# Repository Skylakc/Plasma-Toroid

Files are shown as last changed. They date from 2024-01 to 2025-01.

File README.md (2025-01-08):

# Plasma Toroid DIY Instructions

You can find all the parts for this project in the AliExpress store:
https://www.aliexpress.com/item/1005007423624401.html

or Tindie store:
https://www.tindie.com/stores/simonliu/

For more infomation and cooler gadgets, you can visit our website:
https://haloplasma.com

You can discuss technical issues on Telegram：
https://t.me/+eRFEajIG6_RiMTY1.

[Demo Video](https://youtu.be/MAfQ2tqjaKY)

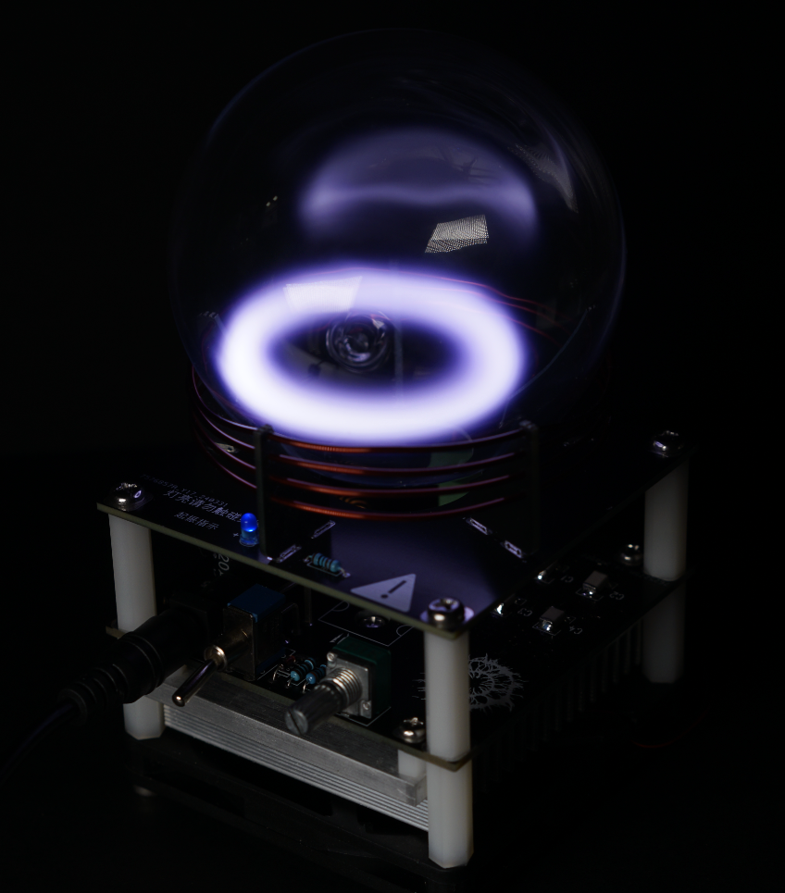
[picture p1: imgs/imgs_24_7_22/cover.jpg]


If you find this document helpful, you can buy me a coffee. We will continue to improve this document.

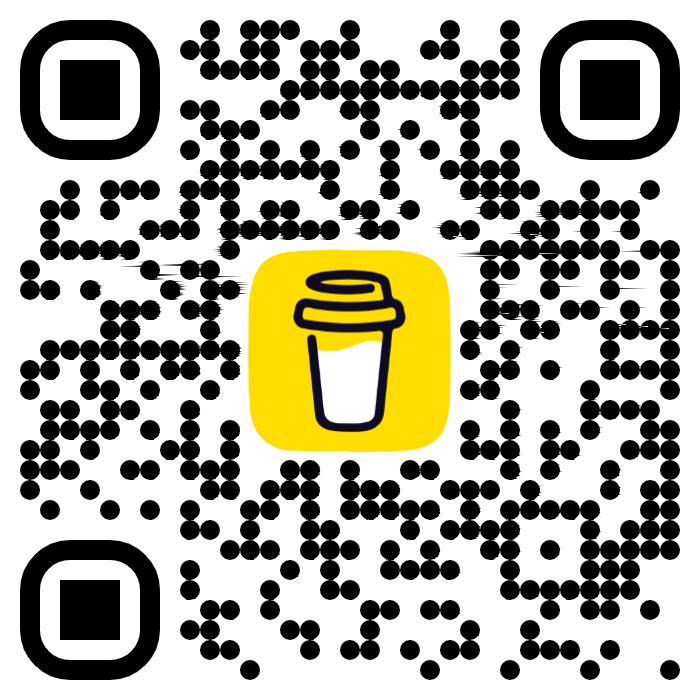
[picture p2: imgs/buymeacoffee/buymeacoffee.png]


## 版权声明©

本仓库版权归属对角巷魔法商店

本仓库遵循 CC-BY-NC-SA协议(即创作共用-署名-非商业性-相同方式共享)且禁止未授权的演绎(截取原工程部分或者在原工程基础上加以修改而诞生的新工程称之为“演绎”)，即使被授权，也要以同样方式共享其工程才方可进行演绎(需要标注原作者署名以及来源)

请大家自觉遵守开源协议，共同维护开源环境。此项目仅供 DIY 以及学习之用，禁止将此项目用于一切商业行为(以牟利为目的贩卖，传播，复制)包括以上三点且不局限于以上三点。

注意!!本产品未授权给任何组织或个人进行销售，如有授权会在此公示。

## 免责声明
在您使用本文档制作等离子环前，请仔细阅读以下重要安全警告和免责说明。使用本文档即表示您已充分了解并同意以下条款：
- 等离子环的危险性：等离子环在运行时玻璃瓶身会产生高温，存在低温烧伤风险。任何时候都不建议用手直接触摸正在运行的玻璃瓶，以免烧伤。
- 磁场警告：等离子环在运行时会产生较强磁场。对于佩戴心脏起搏器及其他医疗设备的人群，强磁场可能会影响设备正常工作。我们建议这部分用户应远离正在工作的等离子环，避免可能的健康风险。
- 高电压风险：等离子环的驱动电路在工作时会产生高电压。高电压存在触电或灼伤的危险，请在电路工作时不要触碰任何元件，包括初级线圈，以免触电或烧伤。
- 元件温度：请注意，电路的某些元件在运行时可能会变得非常热，这可能会造成烫伤。请在设备运行时，特别是长时间运行后，不要触摸这些元件。

使用本文档意味着您已经了解并同意自担使用风险，对于不遵守安全指南而造成的任何直接或间接损害，作者不承担任何责任。

谨慎DIY，安全至上！

## 等离子环（Plasma Toroid）的工作原理解析

  - 辉光放电现象：在特定条件下，气体会在强电场的作用下发生辉光放电。这一过程中，气体分子的电子受激发后跃迁至更高能级轨道。由于这些电子在高能态下并不稳定，它们会自主回落至原始低能轨道，同时根据能量守恒定律释放出能量差对应的光子。这一现象就是辉光放电，它被应用于霓虹灯等装置中。等离子环的发光过程与此类似。

  - 等离子体的性质：除了常见的固体、液体和气态，等离子体是存在于宇宙中的另一种物质状态，火焰便是包含等离子体的例子。当气体受到高温的影响时，分子间的碰撞会使得外层电子脱离其轨道，形成一种由带电粒子组成的等离子体。这种带电的离子混合物具有导电性。
  - 环形电磁场的产生：通过在环形线圈中通入高频交变电流，可以根据麦克斯韦方程组得出其周围电场分布为环形。我们使用自激的Class E震荡电路来生成频率为10MHz左右的交流电。

  - 等离子环的生成过程：在一个封有低压氙气的球形玻璃瓶内，氙气在强电场的作用下被电离，形成等离子体。这些导电的氙气等离子体在外加环形电场的影响下，形成稳定的环状结构。在等离子体中，带电粒子的碰撞产生辉光放电，进而发出淡紫色的光芒，这使得等离子环可见。

**请您在使用和展示等离子环时，确保理解其工作原理和相应的安全措施，以保障使用者的安全。**

## 严正谴责

本项目旨在帮助广大爱好者复现出属于自己的等离子环。然而，近期有无耻商家抄袭此开源项目进行商业行为，严重侵犯本项目著作权。本人在此对此商家的行为进行严正谴责。

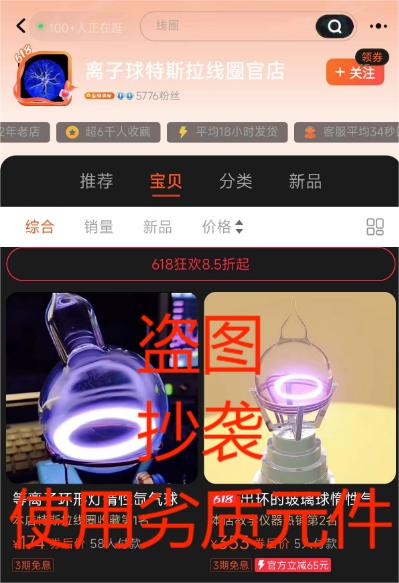
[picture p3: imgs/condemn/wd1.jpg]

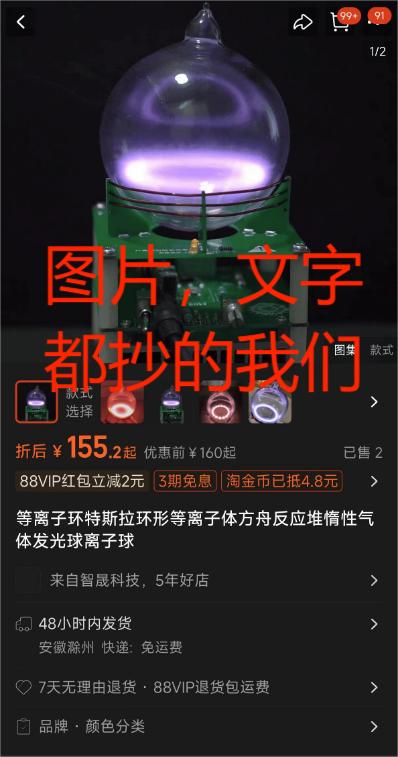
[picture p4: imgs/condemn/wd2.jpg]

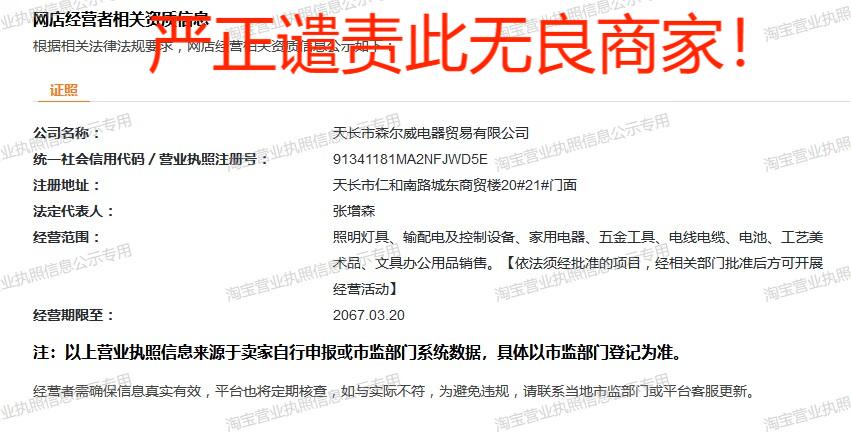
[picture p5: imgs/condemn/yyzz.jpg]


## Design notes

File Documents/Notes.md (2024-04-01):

# 调试过程的注意事项

作者 *对角巷魔法商店*

[成品效果视频](https://www.bilibili.com/video/BV1YQ4y157gs)

[立创开源平台](https://oshwhub.com/skylake/plasmatoroid-drive-circuit)

[装配教程](./Tutorial.md)

等离子环开源技术交流QQ群 736688139

在将自己的制作资料开源后，我收到了很多的反馈，一些制作与调试的经验总结如下，帮助大家少走弯路。

## 从哪里获取制作资料

最开始我在github，立创平台，b站均发布了教程，但后二者每次修改后审核周期漫长，若要获取最新教程请前往github，部分朋友反应打不开github链接，可能是需要梯子。没有梯子可以前往立创平台，立创平台每次更新会审核2天，期间无法看到资料。另外，有问题获得答案的最快方法是加群直接问我。

## 从哪里买到氙气玻璃球

淘宝有两家售卖氙气玻璃球的，一家价格为400，一家价格为160，两种都可以出环，如果觉得贵，关键词搜索爱迪生玫瑰花灯泡，20元左右的灯泡也可以出环。

## 制作时需要注意的

扼流电感选择方面，可以使用10uH的黄环电感，也可以使用自己手绕的电感，手绕的话在2.5cm直径模具上绕制20圈左右即可，手绕的发热更小些。

调整偏置电压的10k电位器建议选择精密电位器，该电位器对能否起振极为关键，该电位器旨在提供3-4V的直流偏置给到mos管G极。直流偏置过低会不起振，过高会电流过大烧坏mos管，调整此电位器一定要极为谨慎！

为了防止炸管，电源一定要有限流功能。如果没有可调电源，可以购买XL4015模块，将其串联在电源上面，将限流拧至3.5a左右即可大大降低电路故障率。

## 调试中需要注意的

一定要**远离**线圈和电容！那里的高压会对你的手**放电**，皮肤会瞬间烧伤！深可及肉~~烤肉的香气~~

电路不建议长时间工作，即使电路不热，玻璃球也可能会很**烫手**。

**非常缓慢**地拧直流偏置电位器，拧到电路刚好起振即可。

可以使用一个氖泡放到线圈附近检验是否起振，如果起振了氖泡会亮。

起振后一般需要用压电陶瓷的高压激发才能出环，成功率最高的激发方法是一个手扶住球上面，另一个手向靠近线圈的位置打火。调整得很好的电路也可以实现自启动。

## 此项目更新状况

目前我们开发出了多个新功能，将会逐步融合到电路里并开源，这些功能已经在实验室里测试成功，但PCB制造出来验证还需要一段时间。

通过在直流偏置处耦合入音频信号，环可以随音乐跳动。
PCB线圈出环成功，使用PCB线圈可以避免手绕线圈的不一致。

通过控制bias电压，可以实现自启动。
氖气玻璃球也可以驱动，拥有极度闪耀的红色

通过调制母线电压和bias，等离子环会产生更多形状
下一版的PCB已经在路上了，在调试成功后这些功能会逐步加入到github项目中，欢迎朋友们加群持续关注。

---

您的Star是对此项目最大的支持!

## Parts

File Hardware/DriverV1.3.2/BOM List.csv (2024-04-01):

Comment | Description | Designator | Footprint | LibRef | Quantity
1K |  | 1K | 1W 金属膜 | 1W 电阻 | 2
RK097 |  | 1K | RK097 电位器 |  | 1
1N4739 | 稳压二极管 | 1N4739 | DO-41 | 稳压二极管 | 1
Resistor |  | 2.7K | 1/4W 金属膜 | 1/4W 电阻 | 1
Resistor |  | 5.6K | 1/4W 金属膜 | 1/4W 电阻 | 1
220uF |  | 220uF | 10MM 电容 | 10mm 电解 | 2
472 | 贴片电容 | 472 | 1812_C | 1206 电容 | 2
330 |  | C1, C2, C3, C4 | 10MM 瓷片 | 10MM 瓷片电容 | 4
FAN |  | FAN | HX2.54-2 | HX-2.54 | 1
10uH |  | L1 | 6826 卧 | 6826电感 | 1
IRFP260 | MOS(场效应管) | MOS | TO-247卧式A | NMOS | 1
OUTPUT |  | OUTPUT | KF142R-3 | HX-2.54 | 1
INPUT |  | P2 | DC005 | HX-2.54 | 1
P6KE15CA | 双向TVS | P6KE15CA | DO-15 TVS | TVS | 1
Switch |  | S1 | MS102-C4 |  | 1
M4*30 | 单头六角尼龙柱 |  |  |  | 4
M4*30 | 平头六角尼龙柱 |  |  |  | 4
M4*30 | 螺钉 |  |  |  | 4
M4*5 | 螺钉 |  |  |  | 4
M3*6+6 | 铜柱
M3*5 | 螺钉
M3*10 | 螺钉
打火机点火器
TO-247导热垫

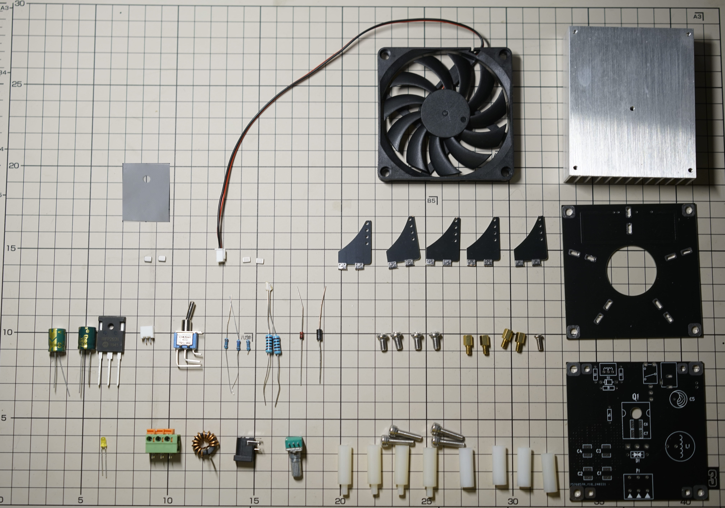
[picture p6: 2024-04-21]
imgs/imgs_24_4_13/FullComponents.JPG

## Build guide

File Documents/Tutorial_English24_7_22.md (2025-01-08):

# Plasma Toroid DIY Instructions

This document was updated on Sep 14, 2024.

Author: *Diagon Alley Magic Shop*

All components used in this document can be found in the Aliexpress store ***Diagon Alley Magic Shop***. 

[Aliexpress link](https://www.aliexpress.com/item/1005007423624401.html)

[Plasma Toroid Principle](https://www.youtube.com/watch?v=GbMAvn7nRWo)

[Finished product demo video YouTube](https://youtu.be/MAfQ2tqjaKY)

[Cooler gadgets in our website](https://haloplasma.com) 

Plasma toroid open source technology telegram group:
https://t.me/+eRFEajIG6_RiMTY1



## Copyright Notice©

This document is for personal learning and plasma toroid manufacturing only. Without the author's consent, no one may modify, republish, or distribute the content of this document. It is strictly prohibited to use this document for any commercial activities.

## Disclaimer
Before using this document to make a plasma toroid, please carefully read the following important safety warnings and disclaimers. Using this document means that you fully understand and agree to the following terms:
- Dangers of plasma toroids: The glass bottle will generate high temperatures when the plasma toroid is running, and there is a risk of low-temperature burns. It is never recommended to directly touch the running glass bottle with your hands to avoid burns.
- Magnetic field warning: The plasma toroid will generate a strong magnetic field during operation. For people wearing pacemakers and other medical devices, strong magnetic fields may affect the normal operation of the devices. We recommend that these users stay away from working plasma toroids to avoid potential health risks.
- High voltage risk: The drive circuit of the plasma toroid will generate high voltage during operation. High voltage poses a danger of electric shock or burns. Please do not touch any components, including the primary coil, while the circuit is working to avoid electric shock or burns.
- Component temperature: Please note that some components of the circuit may become very hot during operation, which may cause burns. When the device is running, especially after running for a long time, do not touch these components.
- Electromagnetic interference: The plasma toroid will emit electromagnetic waves around 10MHz when running. This band will not harm the human body, but it may interfere with some electronic devices operating in this band, such as touchpads and card readers. Please keep these devices away from the working drive circuit.

Using this document means that you understand and agree to bear the risks of use. The author is not responsible for any direct or indirect damages caused by not following the safety guidelines.

DIY with caution, safety first!

## Analysis of the Working Principle of Plasma Toroids

  - Glow discharge phenomenon: Under certain conditions, the gas will undergo glow discharge under the action of a strong electric field. In this process, the electrons of the gas molecules are stimulated and jump to higher energy level orbits. Since these electrons are unstable in the high-energy state, they will spontaneously fall back to the original low-energy orbit while releasing photons corresponding to the energy difference according to the law of conservation of energy. This phenomenon is called glow discharge and is applied to devices such as neon lights. The luminescence process of plasma toroids is similar to this.

  - Properties of plasma: In addition to the common solid, liquid, and gas states, plasma is another state of matter that exists in the universe, and flames are an example that contains plasma. When the gas is affected by high temperature, collisions between molecules will cause the outer electrons to escape their orbits, forming a plasma composed of charged particles. This charged ion mixture has electrical conductivity.
  - Generation of toroidal electromagnetic field: By passing a high-frequency alternating current through a toroidal coil, it can be derived from Maxwell's equations that the electric field distribution around it is toroidal. We use a self-excited Class E oscillator circuit to generate an alternating current with a frequency of about 10MHz.

  - Generation process of plasma toroid: In a spherical glass bottle filled with low-pressure xenon gas, the xenon gas is ionized under the action of a strong electric field to form a plasma. These conductive xenon gas plasmas form a stable toroidal structure under the influence of an external toroidal electric field. In the plasma, collisions of charged particles produce glow discharge, which emits a pale purple light, making the plasma toroid visible.

**When using and demonstrating the plasma toroid, please ensure that you understand its working principle and corresponding safety measures to ensure the safety of users.**

## Preparation of Materials

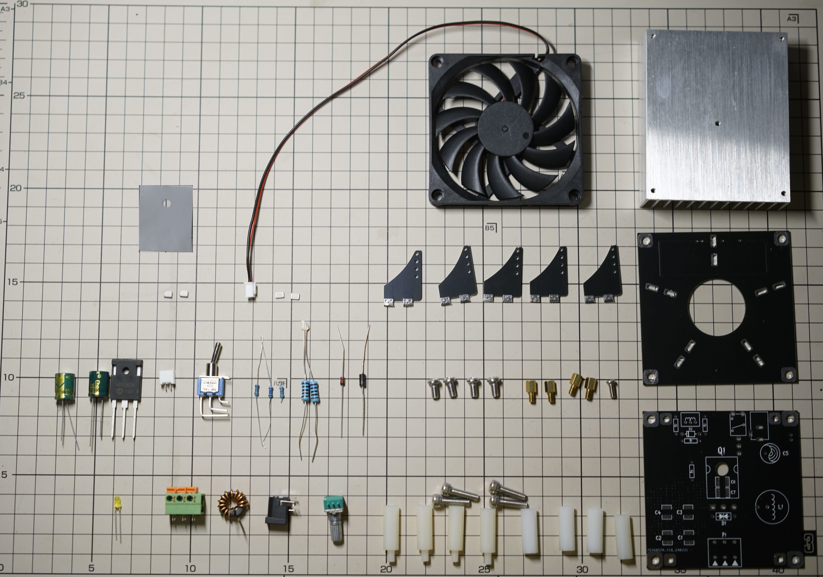
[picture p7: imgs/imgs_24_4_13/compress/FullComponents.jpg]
 

- 80mm glass bottle filled with xenon gas (available in Aliexpress store **Diagon Alley Magic Shop**, larger glass balls cannot be installed in the bracket of this project)
- 1.2mm enameled wire - for winding coils
- Black ring inductor 10uH  
- Circuit board PCB (can be made using the files in the hardware folder)
- Coil support, including base plate and five support pieces
- Heatsink and fan
- MOSFET IRFP260N
- MOSFET heatsink silicone pad
- Potentiometer 1k  
- Resistor 1k * 3
- Resistor 1.8k, 3k
- SMD capacitor 100pf * 4
- SMD capacitor 4.7nF * 2  
- TVS 15V P6KE15CA
- Voltage regulator diode 9.1V
- Input filter capacitor Electrolytic capacitor 63V 220uf
- Toggle switch
- Green terminal block - for connecting coil
- White fan socket
- DC power interface 
- Light emitting diode
- Screws and nylon columns
- Piezoelectric ceramic removed from a lighter (used for initial ignition; this item is prohibited in air transport, so you may need to prepare it yourself, but the circuit can still be made without it)
- XL4015 current limiting module (this module is not required if you have an adjustable power supply)
- 24V power adapter (4A or above, or you can use an adjustable power supply)

## Production Tutorial 
Difficulty ★★★☆☆

### Tools
- Multimeter
- Soldering iron
- Solder wire
- Utility knife
- Diagonal pliers
- Hex screwdriver set 
- Tweezers (for soldering SMD capacitors)

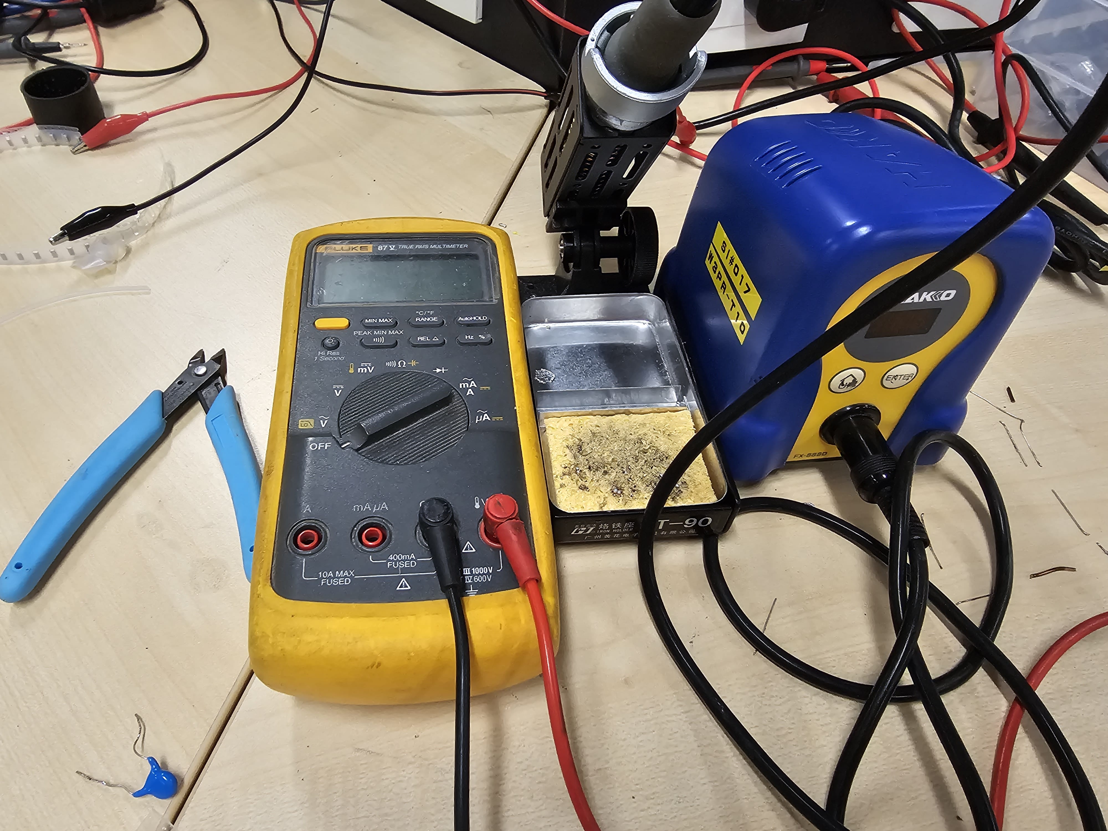
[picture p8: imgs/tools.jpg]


### Steps
- Prepare the five coil brackets, insert them into the base, heat up the soldering iron, and solder them in place with solder. Try to ensure that the brackets are perpendicular to the base plate. (The five coil bracket pieces need some force to fit in)

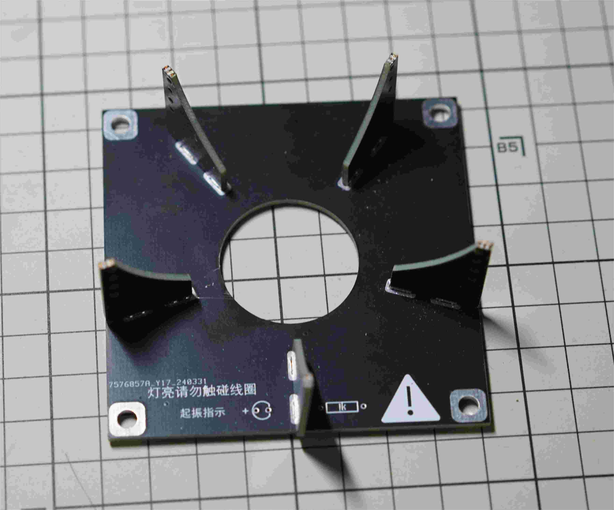
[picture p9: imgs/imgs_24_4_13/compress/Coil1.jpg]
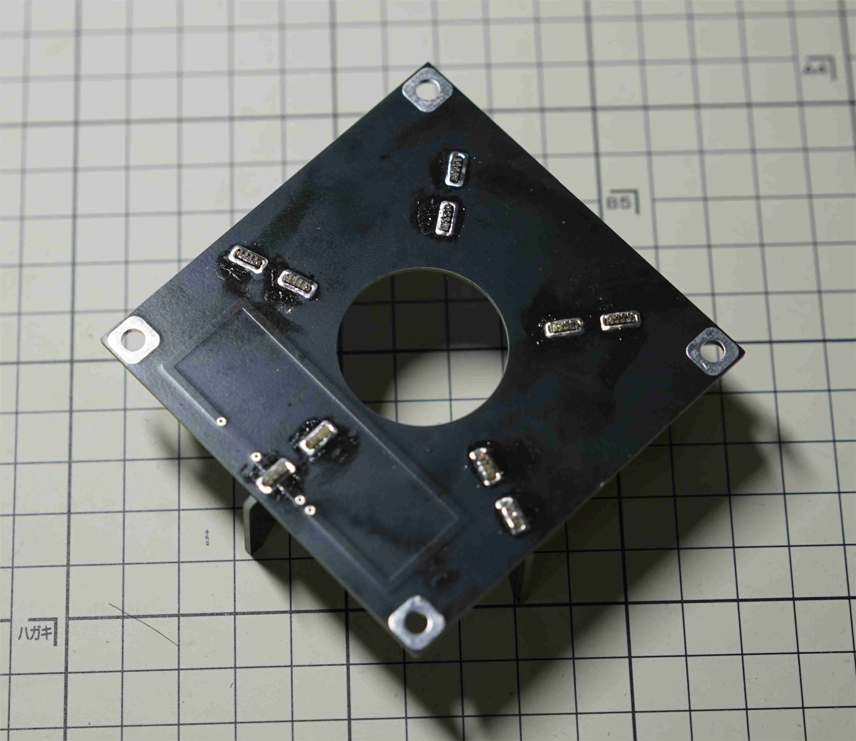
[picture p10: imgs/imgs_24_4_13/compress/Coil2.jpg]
 

- Bend the enameled wire according to the diameter of the coil frame, do not straighten the enameled wire, keeping the enameled wire bent helps with threading, once straightened it cannot be threaded.

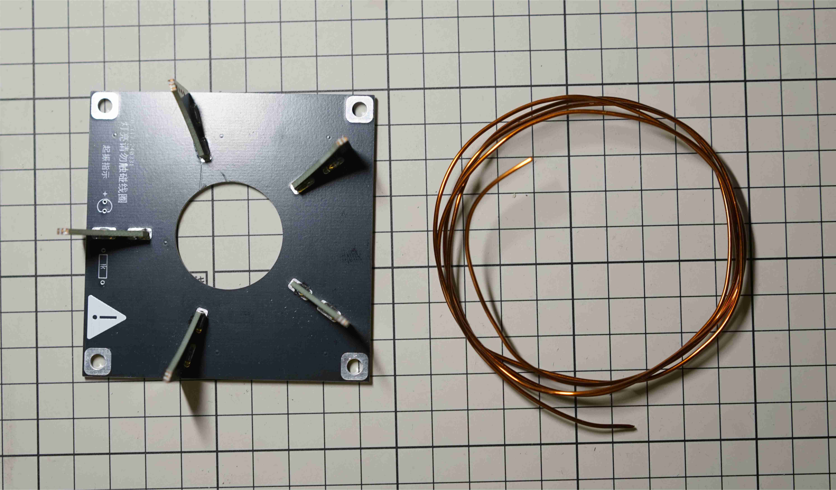
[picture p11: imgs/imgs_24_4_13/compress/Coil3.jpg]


- Thread the enameled wire through the small holes from top to bottom, a total of four turns. The holes are relatively small, and threading can be done by pushing and pulling.

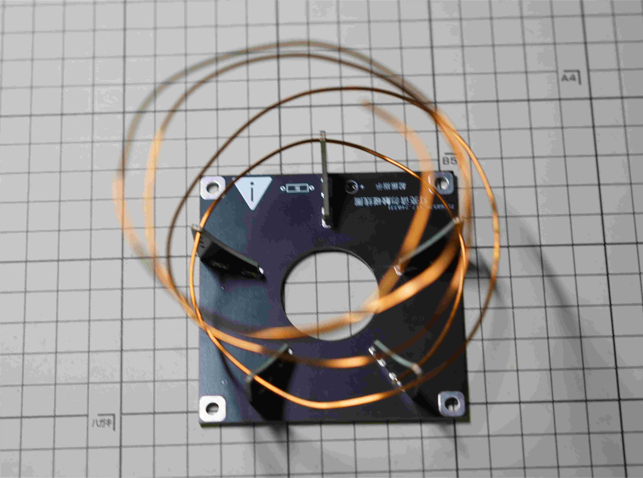
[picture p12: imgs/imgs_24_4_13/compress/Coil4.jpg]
 
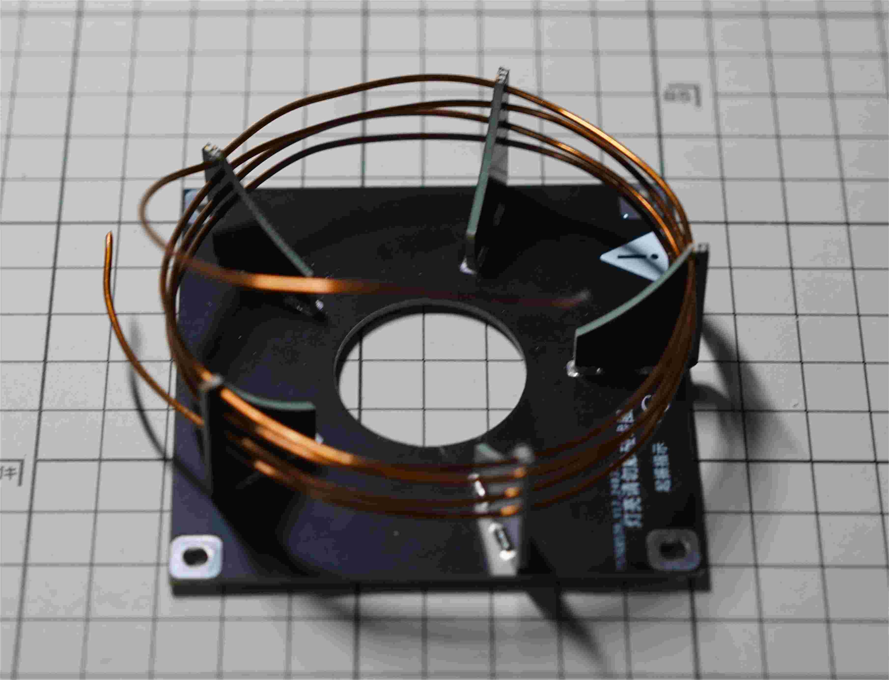
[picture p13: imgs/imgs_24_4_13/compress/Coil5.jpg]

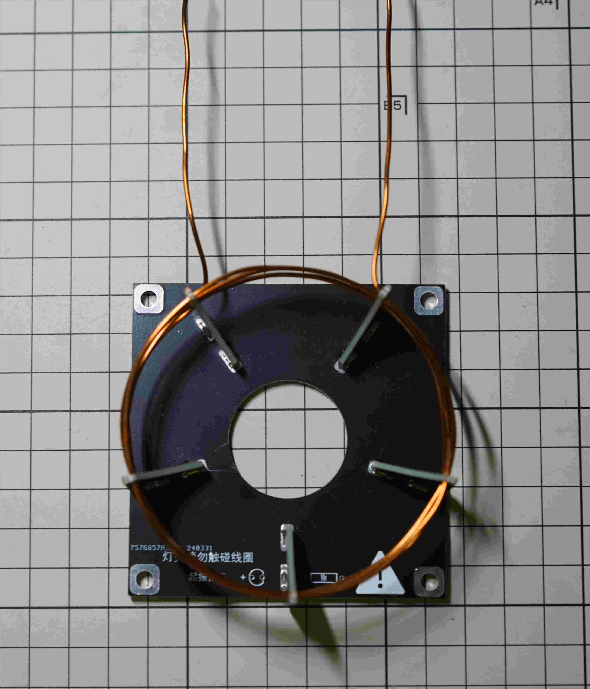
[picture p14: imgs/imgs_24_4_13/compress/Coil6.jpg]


- Make a power supply with current limiting protection (this step can be skipped if you already have an adjustable power supply), prepare a 24V power supply and XL4015 current limiting module, cut the power cord, connect the module in series in the middle, turn the potentiometer for adjusting the output voltage of the XL4015 module clockwise to the end (there will be a clicking sound when turned to the end), and turn the current limiting potentiometer to the 3.5A position. The method to determine the position of the current limiting potentiometer is: set the multimeter to the 10A current range, insert the test leads into the 10A hole, touch the two test leads to the output (at this time, the output is shorted, there may be electric sparks but it's okay), the value displayed on the multimeter is the current limiting value of the current limiting module. Note that using a power supply without current limiting can easily burn out the MOSFET, you must connect the XL4015 module in series before connecting power. If you already have an adjustable power supply, you can skip this step. In the picture below, the potentiometer on the left side of the module is for adjusting the output voltage, and the potentiometer on the right is for adjusting the current limit. Turning clockwise increases the value.
- If you are using an adjustable power supply, please use the current limiting mode (CC), set the output voltage to 24V, and the current limit to 3.5A.

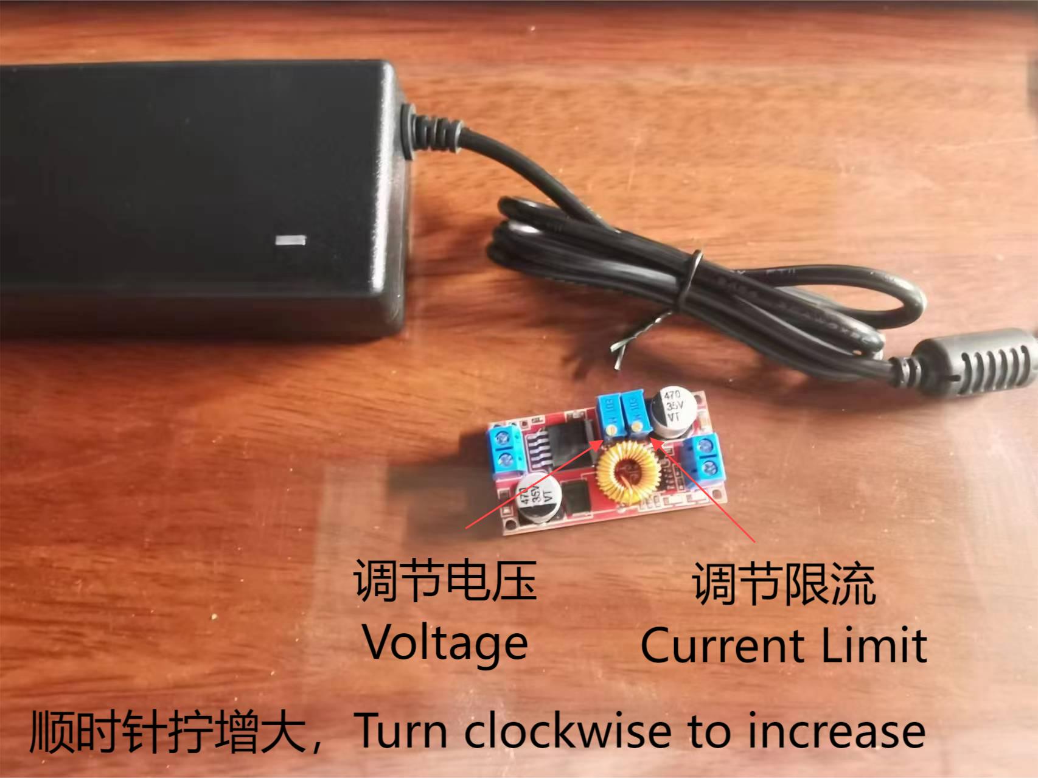
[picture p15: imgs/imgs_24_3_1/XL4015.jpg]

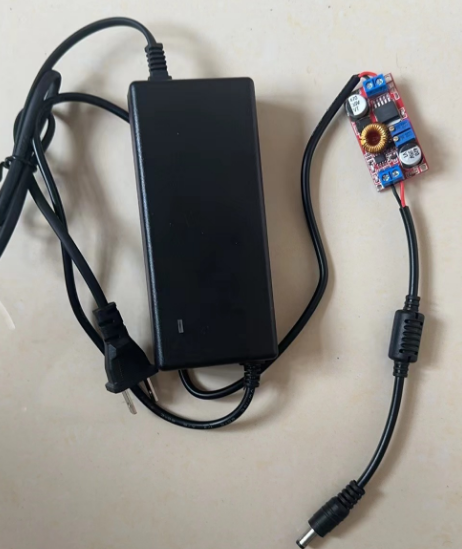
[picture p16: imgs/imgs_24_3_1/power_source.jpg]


- Insert components into the circuit board according to their type (do not install the MOSFET yet). For easy soldering, you can slightly bend the pins to fix them. Note that **the fan connector should be mounted on the back of the PCB, and a light-emitting diode and 1k resistor should also be soldered on the coil bracket PCB**.
The installation positions of each component are shown in the table below.

| Component Name | Installation Position |
|---|---|
| 1k resistor * 3 | R1, R4, coil bracket PCB |
| Light emitting diode | coil bracket PCB |
| 3k resistor | R2 |
| 1.8k resistor | R3 |
| Voltage regulator diode| D2 |
| TVS (black) | D1 |
| Green terminal block | P1 |
| White terminal block | P3 (mounted on the back) |
| 220uf electrolytic cap | C5 |
| 100pf capacitor * 4 | C1, C2, C3, C4 |
| 4.7nf capacitor * 2 | C6, C7 |
| 10uH inductor | L1 |
| IRFP260 | Q1 (do not install this yet) |
| Switch | |
| DC5525 black power jack| |
| B1K single potentiometer | |

- It is recommended to solder the shorter components first, then the taller components, such as soldering the SMD capacitors, resistors, voltage regulators, terminal blocks, etc. first, and finally soldering the electrolytic capacitors and switch. If you have no soldering experience, be sure to search for soldering tutorials on Bilibili to learn first. According to historical statistics, 60% of people who had problems after making it were due to poor contact between components and PCB caused by not mastering the correct soldering method.
  
  > Resistor identification 
  >  - 1k resistor has a brown line
  >	 - 1.8k resistor has a brown line and a gray line  
  >	 - 3k resistor has an orange line
  >	 If you really can't tell them apart, just measure with a multimeter ^_^

  > Capacitor identification
  >  - 4.7nF capacitors are relatively thinner
  >	 - 220pF/100pF capacitors are relatively thicker
  >  - For resonant capacitors, you can choose two 220pF or four 100pF

  > Diode direction identification
  >  - The black TVS is non-directional
  >	 - The red voltage regulator diode needs to be directional, the black line on the voltregulator diode should match the white line position on the PCB silkscreen.age 

  > Some friends may not know how to solder SMD components, you can search for SMD component soldering tutorials on Youtube to learn. Simply put, solder one side first to fix the SMD component, then solder the other side.
  >【How To Solder SMD Correctly - Part 1 /SMD Soldering Tutorial - Youtube】 https://www.youtube.com/watch?v=EW9Y8rDm4kE

  > Be sure to pay attention to the direction of the electrolytic capacitor, soldering it backwards may cause intense heating or even explosion. The longer leg of the electrolytic capacitor is the positive electrode, and the side with the stripe mark is the negative electrode. Please refer to the picture below to install the electrolytic capacitor correctly.

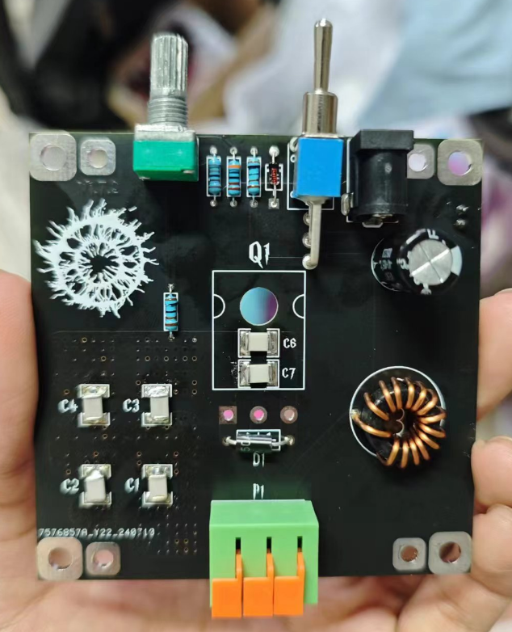
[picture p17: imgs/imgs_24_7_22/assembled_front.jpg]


- When soldering, **be careful of the high temperature of the soldering iron to avoid burns.**

- After all components are soldered, cut off the pins. Please try to ensure that the solder joints are full and smooth, and start from the root when removing the pins.

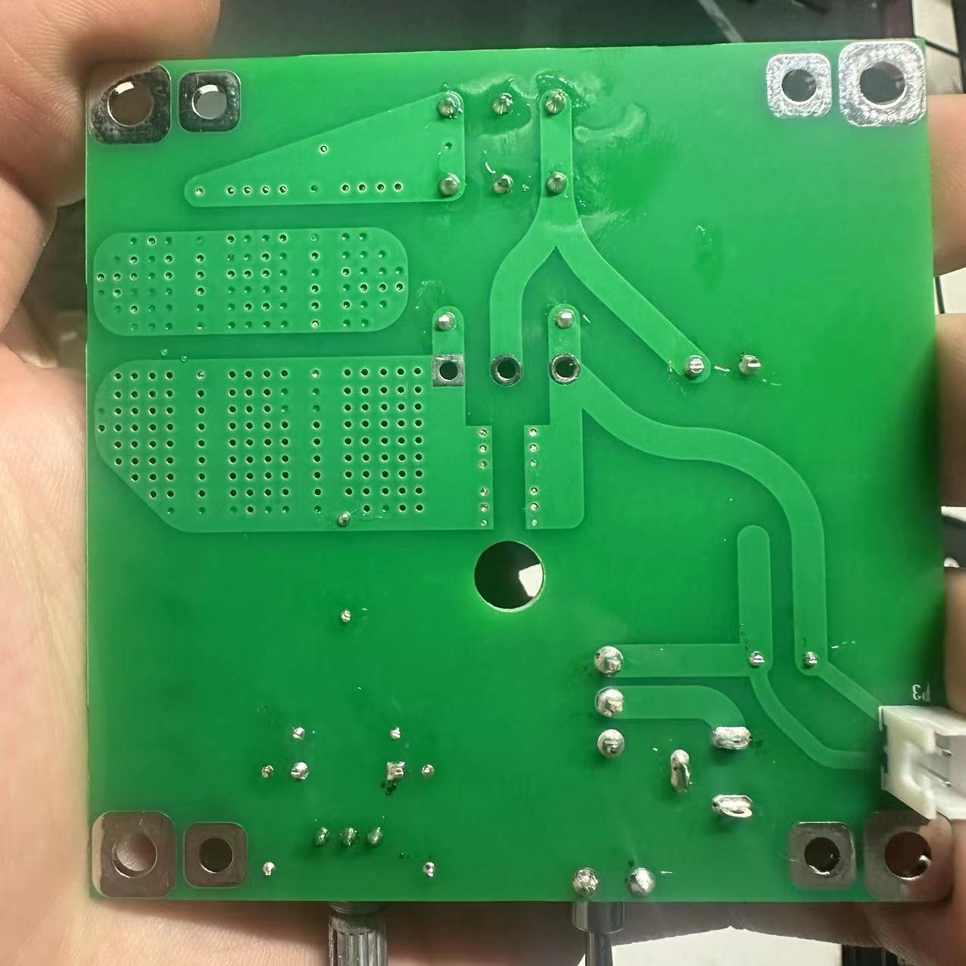
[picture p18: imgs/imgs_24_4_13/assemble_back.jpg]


- Screw 6mm copper columns (or 6mm nylon columns) into the screw holes around the heatsink.

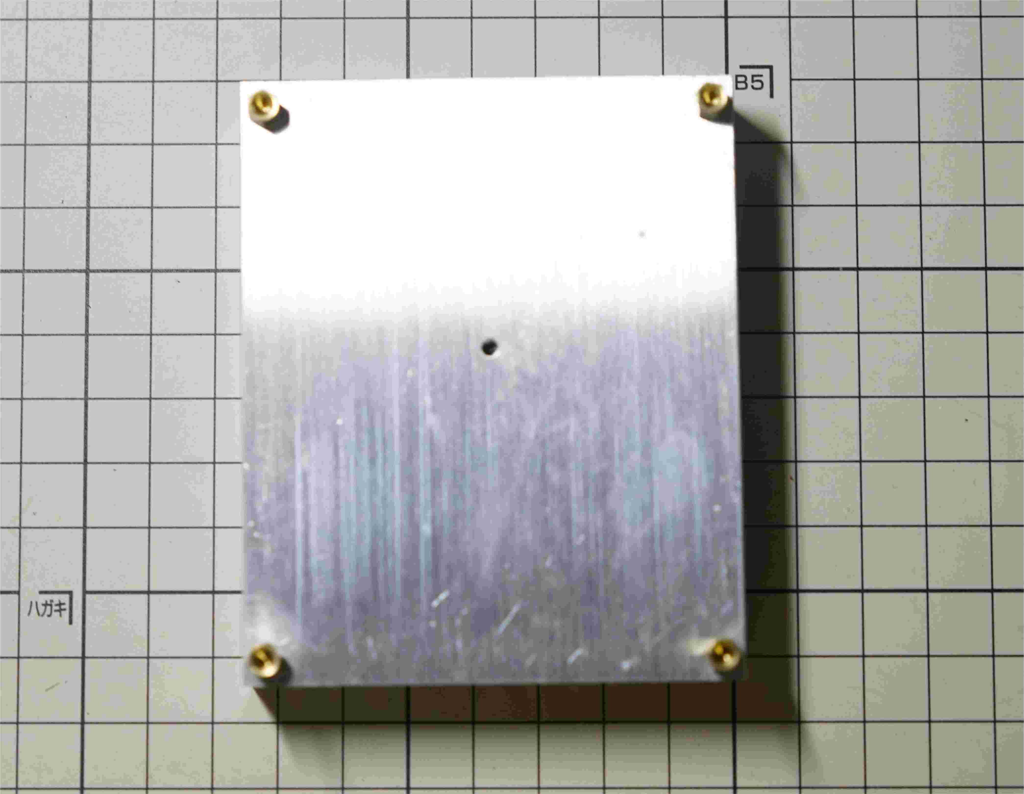
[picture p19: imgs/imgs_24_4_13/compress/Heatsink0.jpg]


- Install the MOSFET. Place the side of the MOSFET with text **facing up**, pad the other side with a silicone pad and fix it on the heatsink with screws, with the pins **facing downward**. At this time, the pins from left to right are G, D, and S poles respectively.

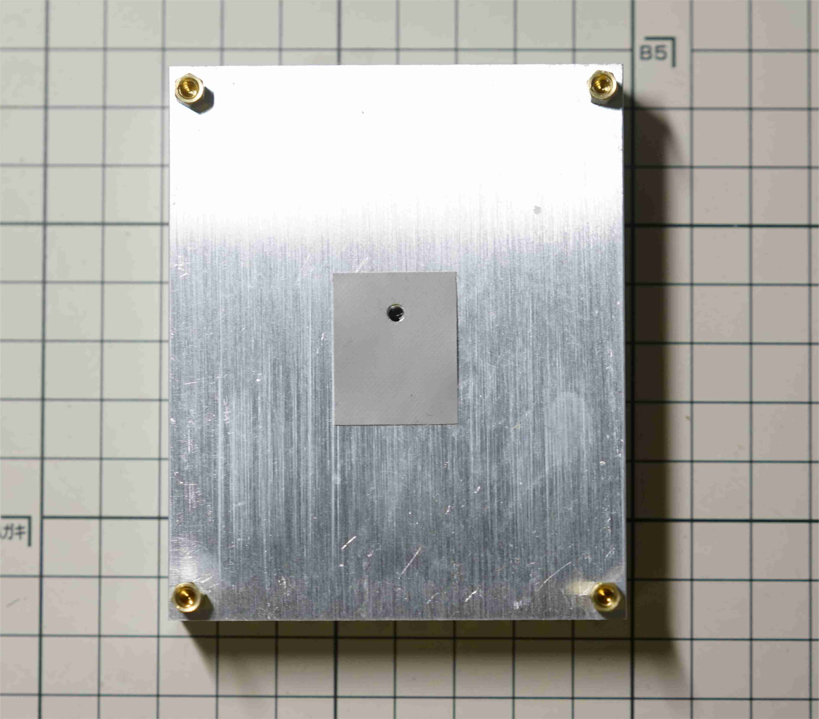
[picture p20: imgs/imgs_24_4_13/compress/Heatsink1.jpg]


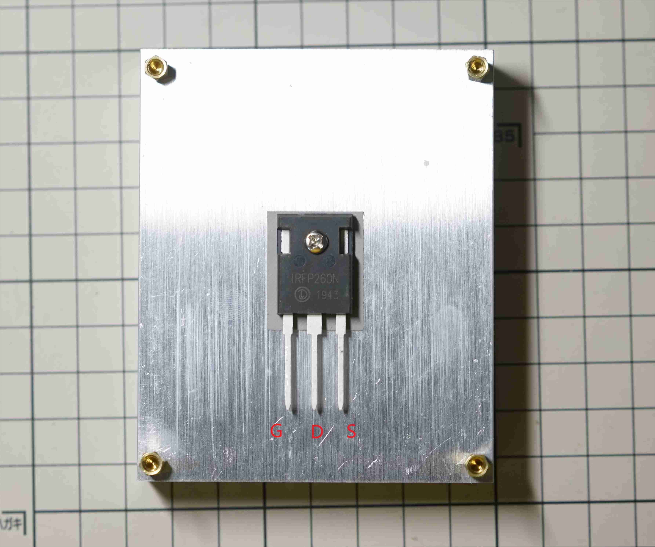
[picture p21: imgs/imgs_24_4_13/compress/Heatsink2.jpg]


- Bend the pins and insert them into the PCB. **First align the holes of the PCB and the heatsink to ensure that the four screws can be tightened**, then solder the MOSFET.

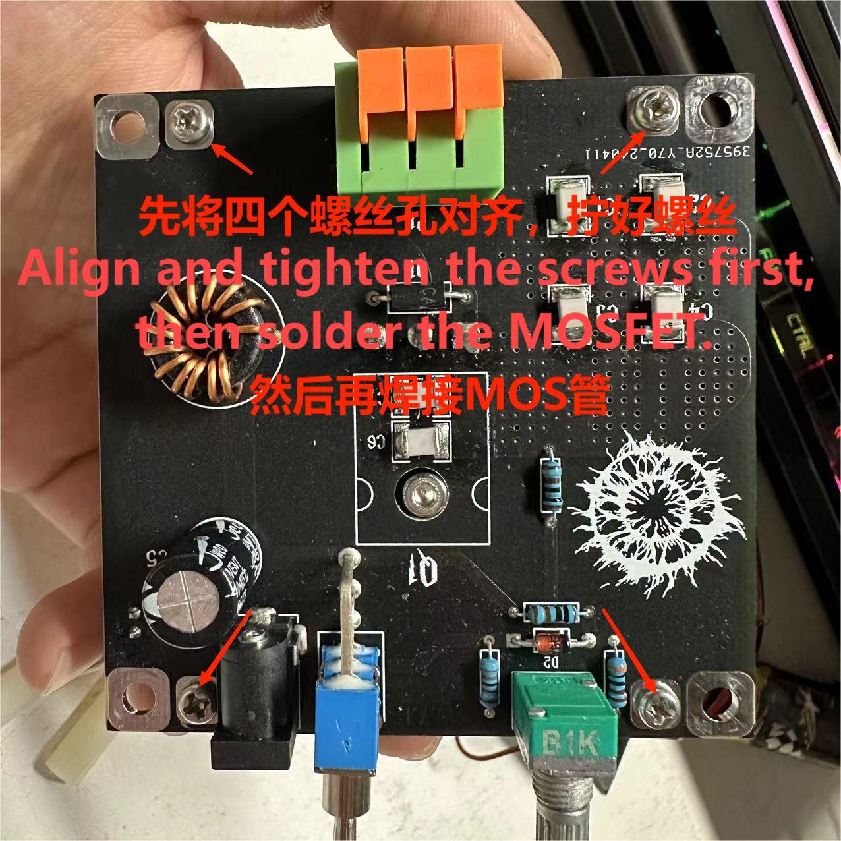
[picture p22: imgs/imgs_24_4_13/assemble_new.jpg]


- Fix the fan. The connection of all layers is shown in the figure below. The fan's airflow is blowing towards the heatsink (blowing upward).

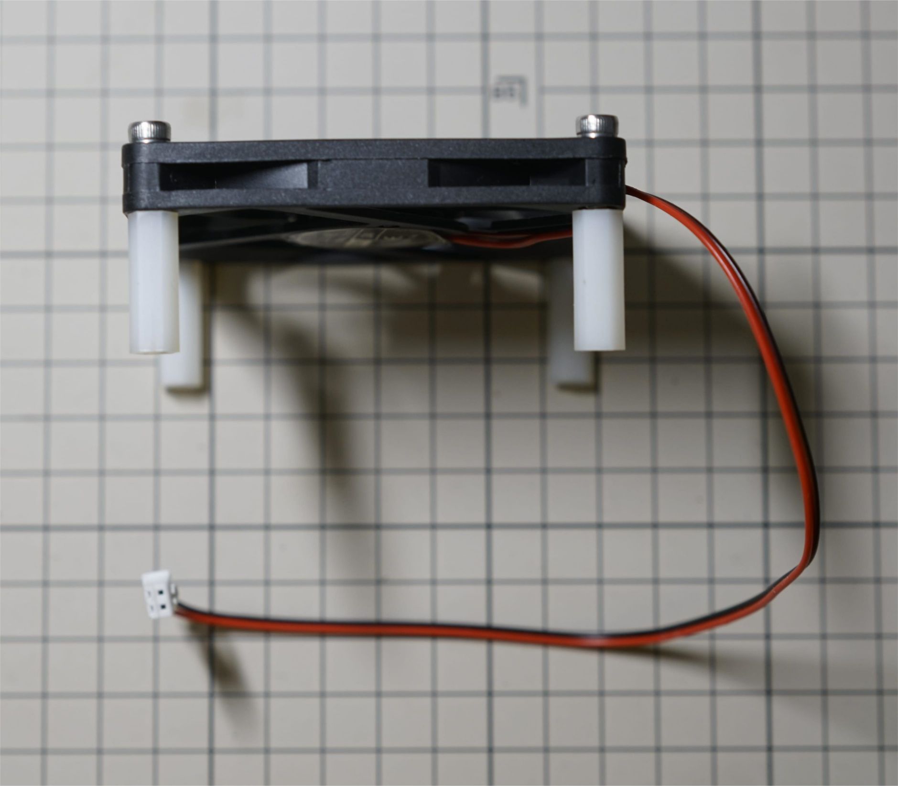
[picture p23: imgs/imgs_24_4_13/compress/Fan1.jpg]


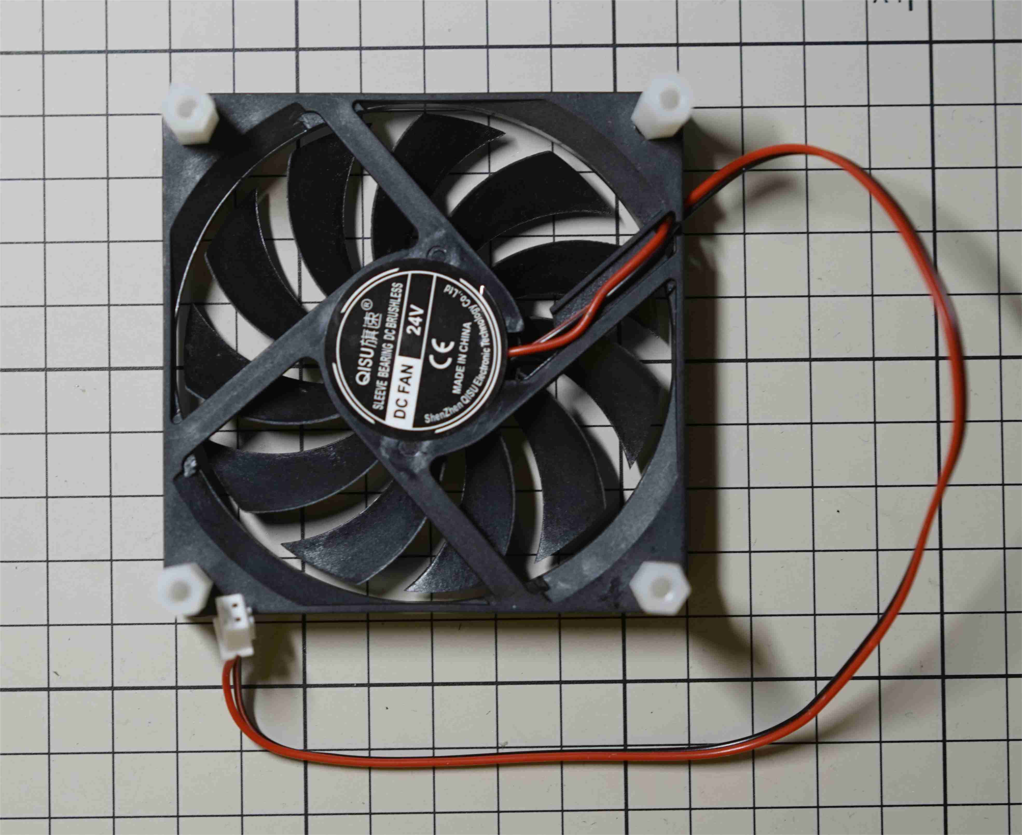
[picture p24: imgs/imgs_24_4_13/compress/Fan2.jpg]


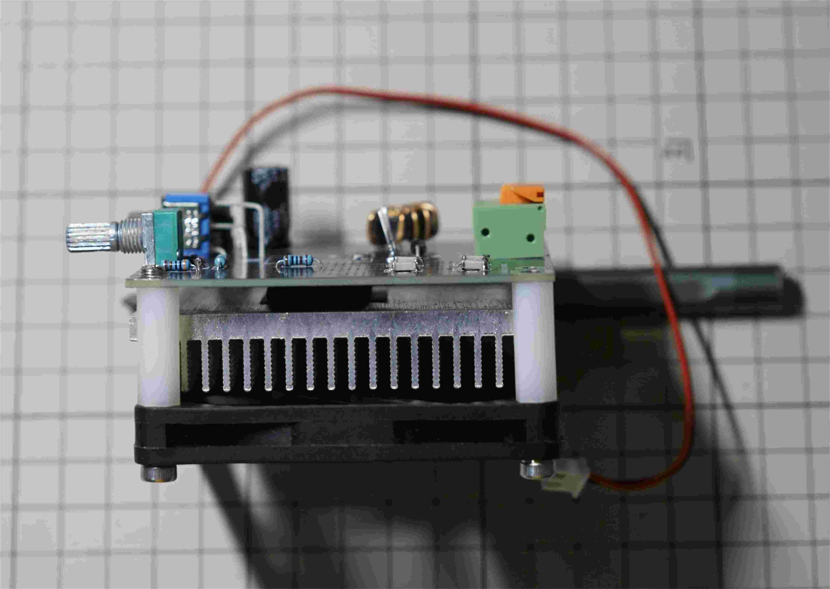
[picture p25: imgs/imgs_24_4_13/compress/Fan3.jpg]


- Use screws to mount the coil bracket to the top, with the two wires facing the green coil terminal block.

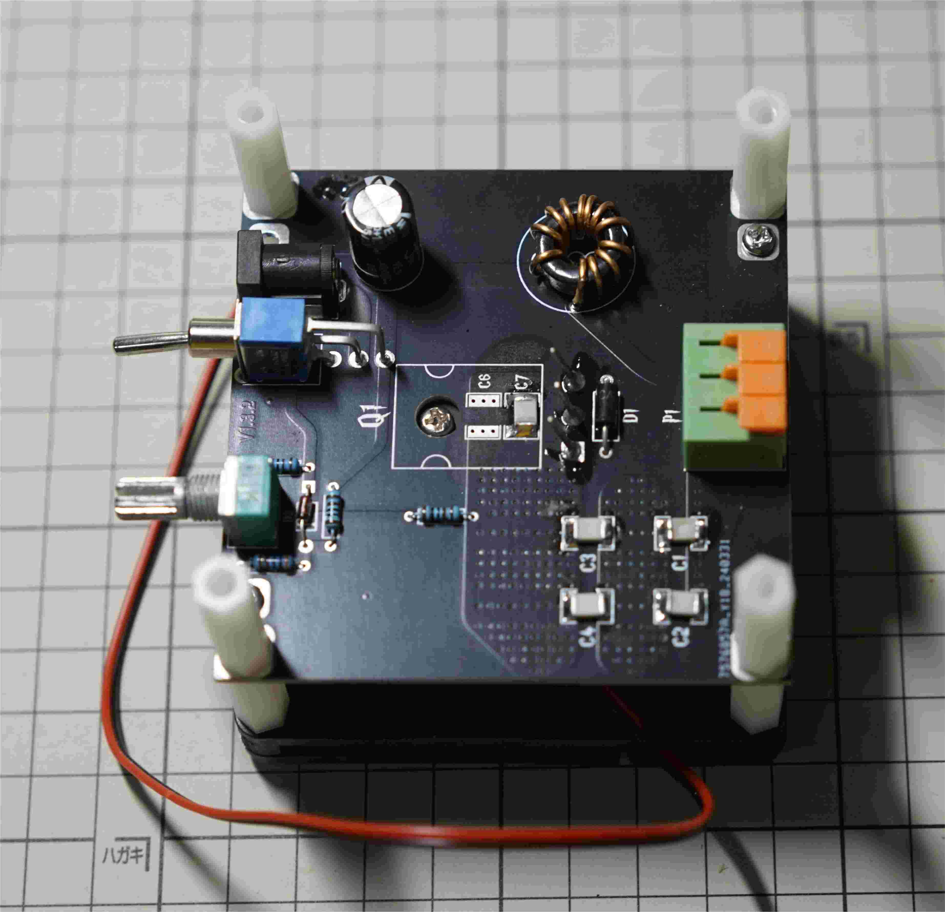
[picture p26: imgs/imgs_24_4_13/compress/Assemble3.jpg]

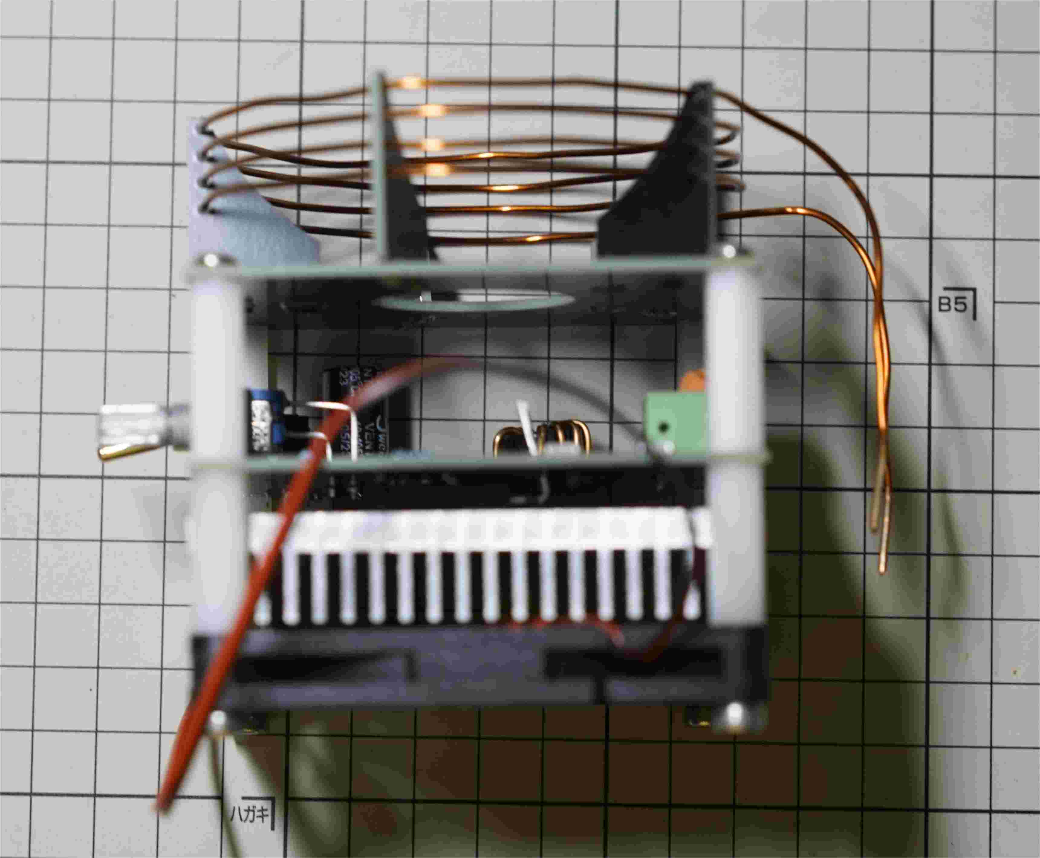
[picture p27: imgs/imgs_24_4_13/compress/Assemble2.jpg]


- Cut the enameled wire appropriately so that it can be inserted into the terminal block.
- Use a utility knife to scrape off the enamel at the end of the wire to expose the copper core inside the enameled wire.
- **Note: Be sure to scrape the enamel at the end of the wire clean, otherwise poor contact may prevent it from working!**

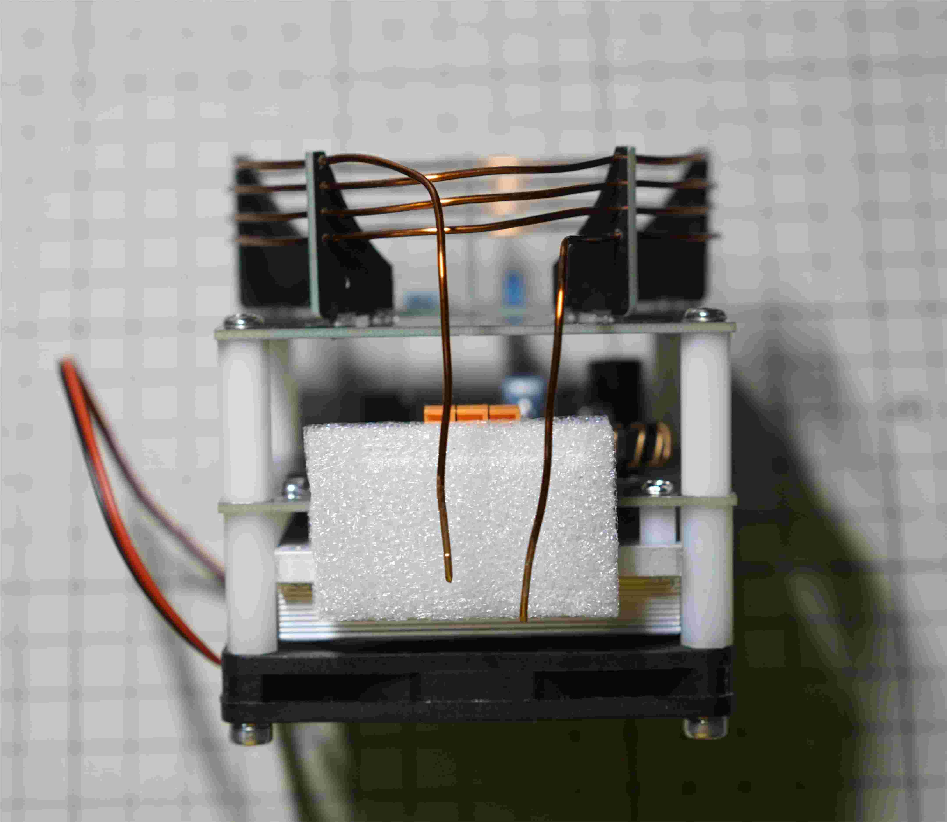
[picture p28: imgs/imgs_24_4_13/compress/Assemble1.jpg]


- Insert the two wires of the coil into pins 1 and 3 of the green terminal block (the middle hole is not used), and insert the fan power cord into the fan interface on the back of the PCB.

- After confirming that all parts are properly connected again, you can prepare to power on o(*￣▽￣*)ブ

- If you are using an adjustable power supply, please use the current limiting mode (CC), set the output voltage to 24V, and the current limit to 3.5A.
- Put on the bottle and make sure the potentiometer is at the maximum counterclockwise position.

- Before powering on, please carefully read the safety instructions:
  >  Stay away from the coil when the circuit is working, as the high temperature of the coil may cause burns.

  >  You can rotate the bottle, but the bottle will also heat up. Be careful and keep your hands away from the coil (at least 1cm away) when rotating the bottle.

  >	 You can turn the potentiometer while the circuit is working, but do not hold the bottle with one hand and touch the potentiometer on the circuit with the other hand, because the high-voltage static electricity on the bottle can damage the circuit.

  >	 The circuit will heat up. It is not recommended to run the circuit for a long time. It is recommended to work continuously for no more than two minutes.

  >	 After use, remember to turn off the switch and disconnect the power supply.

- After ensuring that you have read the safety instructions, plug in the power supply and turn on the switch. At this time, the fan should start spinning.

- Turn the potentiometer clockwise. When it is turned about halfway, the circuit will start working. When the circuit starts working, the LED next to the coil will light up. At this point, use a lighter to point at the bottle and click it to generate the toroid. If the lighter fails to generate the toroid, you can turn the potentiometer clockwise a little more and try again.
  
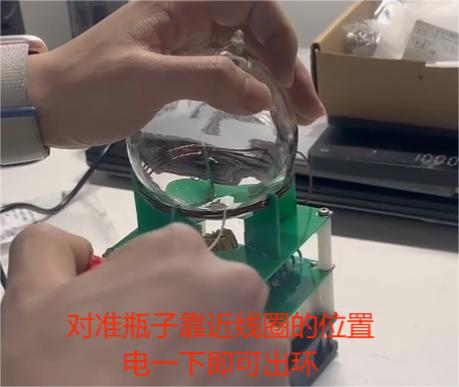
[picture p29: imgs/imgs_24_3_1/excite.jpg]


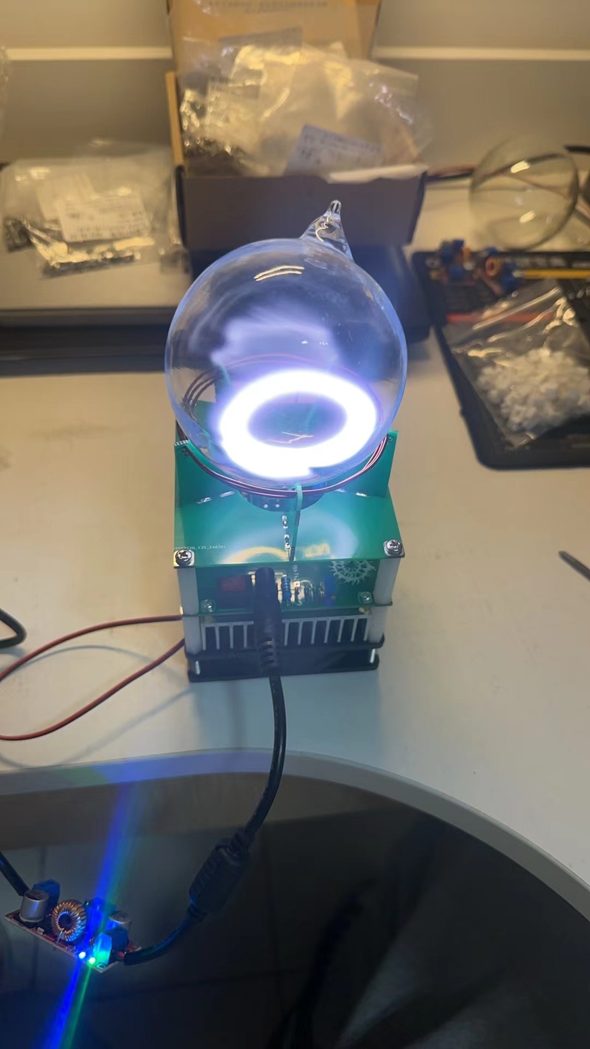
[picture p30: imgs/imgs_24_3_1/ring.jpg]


- Sometimes, your bottle may glow white without generating a toroid (as shown below). Adjusting the bottle position and re-igniting it a few times usually fixes it.

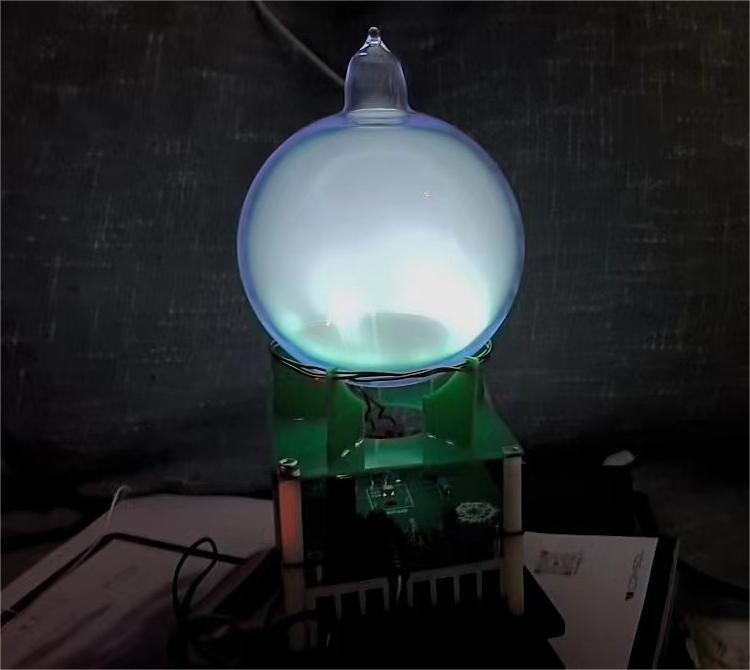
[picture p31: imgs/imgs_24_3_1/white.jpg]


- After the toroid is generated, slightly turning the potentiometer will cause some changes in the shape of the toroid. If the toroid disappears, re-igniting it will generate it again.

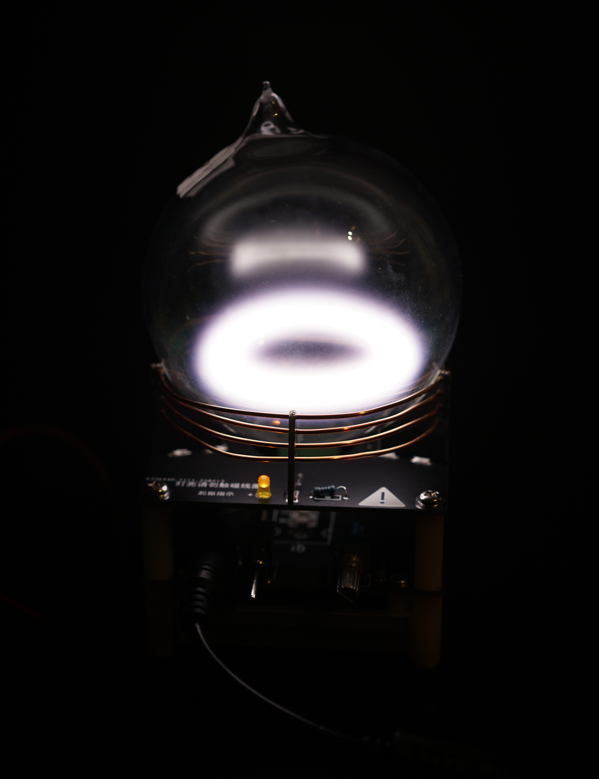
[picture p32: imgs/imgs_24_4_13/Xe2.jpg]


### Reference Circuit Diagram
Since the hardware of this project is still being updated, the circuit diagram is for reference only. The actual circuit should be based on the PCB.
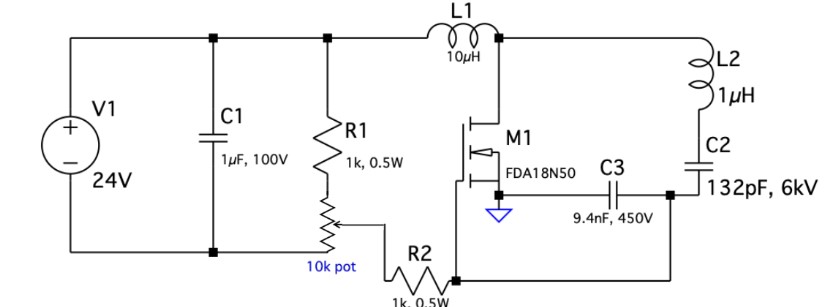
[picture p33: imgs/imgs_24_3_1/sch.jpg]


### FAQ
If you have any questions, join the telegram group：
https://t.me/+eRFEajIG6_RiMTY1.
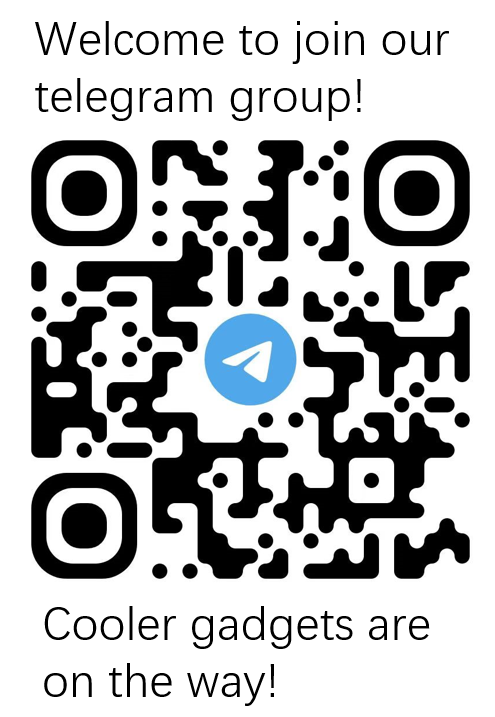
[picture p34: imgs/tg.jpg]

All project developers are in the group, and you can get answers at the fastest speed.(We try to answer all your questions within 24 hours.)

#### Acknowledgments: 
Tate McAluney

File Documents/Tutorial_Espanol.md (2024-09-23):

# Instrucciones de bricolaje del toroide de plasma

Este documento fue actualizado el 22 de julio de 2024.

Autor: *Tienda de Magia del Callejón Diagon*

Todos los componentes utilizados en este documento se pueden encontrar en la tienda de Aliexpress ***Tienda de Magia del Callejón Diagon***. 

[Principio del toroide de plasma](https://www.youtube.com/watch?v=GbMAvn7nRWo)

[Video de demostración del producto terminado 1](https://www.bilibili.com/video/BV1Lm411z7tf)

[Video de demostración del producto terminado 2](https://www.bilibili.com/video/BV12f421o7rf) 

[Plataforma de código abierto LCEDA](https://oshwhub.com/skylake/plasmatoroid-drive-circuit)

Grupo de telegram de tecnología de código abierto del toroide de plasma:
https://t.me/+eRFEajIG6_RiMTY1



## Aviso de derechos de autor©

Este documento es solo para aprendizaje personal y fabricación de toroides de plasma. Sin el consentimiento del autor, nadie puede modificar, republicar o distribuir el contenido de este documento. Está estrictamente prohibido utilizar este documento para cualquier actividad comercial.

## Descargo de responsabilidad  
Antes de usar este documento para hacer un toroide de plasma, lea atentamente las siguientes advertencias de seguridad importantes y descargos de responsabilidad. El uso de este documento significa que comprende y acepta completamente los siguientes términos:
- Peligros de los toroides de plasma: La botella de vidrio generará altas temperaturas cuando el toroide de plasma esté funcionando, y existe el riesgo de quemaduras a baja temperatura. Nunca se recomienda tocar directamente la botella de vidrio en funcionamiento con las manos para evitar quemaduras.
- Advertencia de campo magnético: El toroide de plasma generará un fuerte campo magnético durante el funcionamiento. Para las personas que usan marcapasos y otros dispositivos médicos, los campos magnéticos fuertes pueden afectar el funcionamiento normal de los dispositivos. Recomendamos que estos usuarios se mantengan alejados de los toroides de plasma en funcionamiento para evitar posibles riesgos para la salud.  
- Riesgo de alto voltaje: El circuito de accionamiento del toroide de plasma generará alto voltaje durante el funcionamiento. El alto voltaje representa un peligro de descarga eléctrica o quemaduras. No toque ningún componente, incluida la bobina primaria, mientras el circuito esté funcionando para evitar descargas eléctricas o quemaduras.
- Temperatura de los componentes: Tenga en cuenta que algunos componentes del circuito pueden calentarse mucho durante el funcionamiento, lo que puede causar quemaduras. Cuando el dispositivo esté funcionando, especialmente después de funcionar durante mucho tiempo, no toque estos componentes.  
- Interferencia electromagnética: El toroide de plasma emitirá ondas electromagnéticas alrededor de 10 MHz cuando esté funcionando. Esta banda no dañará el cuerpo humano, pero puede interferir con algunos dispositivos electrónicos que operan en esta banda, como paneles táctiles y lectores de tarjetas. Mantenga estos dispositivos alejados del circuito de accionamiento en funcionamiento.

El uso de este documento significa que comprende y acepta asumir los riesgos de uso. El autor no se hace responsable de los daños directos o indirectos causados por no seguir las pautas de seguridad.

¡Hágalo usted mismo con precaución, la seguridad es lo primero!

## Análisis del principio de funcionamiento de los toroides de plasma

- Fenómeno de descarga luminiscente: Bajo ciertas condiciones, el gas experimentará una descarga luminiscente bajo la acción de un fuerte campo eléctrico. En este proceso, los electrones de las moléculas de gas se estimulan y saltan a órbitas de nivel de energía más alto. Como estos electrones son inestables en el estado de alta energía, volverán espontáneamente a la órbita original de baja energía mientras liberan fotones correspondientes a la diferencia de energía de acuerdo con la ley de conservación de la energía. Este fenómeno se llama descarga luminiscente y se aplica a dispositivos como luces de neón. El proceso de luminiscencia de los toroides de plasma es similar a esto.

- Propiedades del plasma: Además de los estados comunes de sólido, líquido y gaseoso, el plasma es otro estado de la materia que existe en el universo, y las llamas son un ejemplo que contiene plasma. Cuando el gas se ve afectado por altas temperaturas, las colisiones entre moléculas harán que los electrones exteriores escapen de sus órbitas, formando un plasma compuesto de partículas cargadas. Esta mezcla de iones cargados tiene conductividad eléctrica.

- Generación de campo electromagnético toroidal: Al pasar una corriente alterna de alta frecuencia a través de una bobina toroidal, se puede derivar de las ecuaciones de Maxwell que la distribución del campo eléctrico a su alrededor es toroidal. Usamos un circuito oscilador Clase E autoexcitado para generar una corriente alterna con una frecuencia de aproximadamente 10 MHz. 

- Proceso de generación del toroide de plasma: En una botella de vidrio esférica llena de gas xenón a baja presión, el gas xenón se ioniza bajo la acción de un fuerte campo eléctrico para formar un plasma. Estos plasmas de gas xenón conductores forman una estructura toroidal estable bajo la influencia de un campo eléctrico toroidal externo. En el plasma, las colisiones de partículas cargadas producen una descarga luminiscente, que emite una luz violeta pálida, haciendo visible el toroide de plasma.

**Cuando use y demuestre el toroide de plasma, asegúrese de comprender su principio de funcionamiento y las medidas de seguridad correspondientes para garantizar la seguridad de los usuarios.**

## Preparación de materiales



- Botella de vidrio de 80 mm llena de gas xenón (disponible en la tienda de Aliexpress **Tienda de Magia del Callejón Diagon**, las esferas de vidrio más grandes no se pueden instalar en el soporte de este proyecto)  
- Alambre esmaltado de 1.2 mm - para enrollar bobinas
- Inductor de anillo negro 10uH
- Placa de circuito impreso PCB (se puede hacer usando los archivos en la carpeta de hardware)
- Soporte de bobina, incluida la placa base y cinco piezas de soporte  
- Disipador de calor y ventilador
- MOSFET IRFP260N
- Almohadilla de silicona para disipador de calor MOSFET
- Potenciómetro 1k
- Resistencia 1k * 3
- Resistencia 1.8k, 3k  
- Condensador SMD 100pf * 4
- Condensador SMD 4,7nF * 2
- TVS 15V P6KE15CA
- Diodo regulador de voltaje 9.1V
- Condensador electrolítico de filtro de entrada 63V 220uf
- Interruptor de palanca  
- Bloque de terminales verdes - para conectar la bobina
- Conector de ventilador blanco
- Interfaz de alimentación CC
- Diodo emisor de luz
- Tornillos y columnas de nylon
- Cerámica piezoeléctrica extraída de un encendedor (para encendido inicial)
- Módulo limitador de corriente XL4015 (este módulo no es necesario si tiene una fuente de alimentación ajustable)
- Adaptador de corriente de 24V (4A o superior, o puede usar una fuente de alimentación ajustable)

## Tutorial de producción
Dificultad ★★★☆☆

### Herramientas
- Multímetro
- Soldador  
- Alambre de soldadura
- Cuchillo multiusos
- Alicates diagonales
- Juego de destornilladores hexagonales
- Pinzas (para soldar condensadores SMD)



### Pasos
- Prepare los cinco soportes de bobina, insértelos en la base, caliente el soldador y suéldelos en su lugar con soldadura. Intente asegurarse de que los soportes estén perpendiculares a la placa base. (Las cinco piezas del soporte de la bobina necesitan algo de fuerza para encajar)

 

- Doble el cable esmaltado de acuerdo con el diámetro del marco de la bobina, no enderece el cable esmaltado, mantener el cable esmaltado doblado ayuda con el enhebrado, una vez enderezado no se puede enhebrar.



- Enhebre el cable esmaltado a través de los pequeños agujeros de arriba hacia abajo, un total de cuatro vueltas. Los agujeros son relativamente pequeños y el enhebrado se puede hacer empujando y tirando.
  
 



- Haga una fuente de alimentación con protección de limitación de corriente (este paso se puede omitir si ya tiene una fuente de alimentación ajustable), prepare una fuente de alimentación de 24V y un módulo limitador de corriente XL4015, corte el cable de alimentación, conecte el módulo en serie en el medio, gire el potenciómetro para ajustar el voltaje de salida del módulo XL4015 en sentido horario hasta el final (habrá un sonido de clic cuando se gira hasta el final), y gire el potenciómetro de limitación de corriente a la posición de 3.5A. El método para determinar la posición del potenciómetro limitador de corriente es: configure el multímetro en el rango de corriente de 10A, inserte los cables de prueba en el orificio de 10A, toque los dos cables de prueba en la salida (en este momento, la salida está en cortocircuito, puede haber chispas eléctricas pero está bien), el valor que se muestra en el multímetro es el valor de límite de corriente del módulo limitador de corriente. Tenga en cuenta que el uso de una fuente de alimentación sin limitación de corriente puede quemar fácilmente el MOSFET, debe conectar el módulo XL4015 en serie antes de conectar la alimentación. Si ya tiene una fuente de alimentación ajustable, puede omitir este paso. En la siguiente imagen, el potenciómetro en el lado izquierdo del módulo es para ajustar el voltaje de salida, y el potenciómetro en el lado derecho es para ajustar el límite de corriente. Girar en sentido horario aumenta el valor.
  
- Si está utilizando una fuente de alimentación ajustable, utilice el modo de limitación de corriente (CC), ajuste el voltaje de salida a 24V y el límite de corriente a 3.5A.




- Inserte los componentes en la placa de circuito según su tipo (no instale el MOSFET todavía). Para facilitar la soldadura, puede doblar ligeramente las patillas para fijarlas. Tenga en cuenta que **el conector del ventilador debe montarse en la parte posterior del PCB, y también se debe soldar un diodo emisor de luz y una resistencia de 1k en el PCB del soporte de la bobina**.
Las posiciones de instalación de cada componente se muestran en la tabla a continuación.

| Nombre del componente | Posición de instalación |
|---|---|
| Resistencia 1k * 3 | R1, R4, PCB soporte de bobina|
| Diodo emisor de luz | PCB soporte de bobina | 
| Resistencia 3k | R2 |
| Resistencia 1.8k | R3 |
| Diodo regulador voltaje | D2 |
| TVS (negro) | D1 |
| Bloque terminal verde | P1 |
| Bloque terminal blanco  | Q3 (montado en la parte posterior)|
| Condensador electrolítico 220uf| C5 |
| Condensador 100pf * 4 | C1, C2, C3, C4 |
| Condensador 4.7nf * 2 | C6, C7 |
| Inductor 10uH | L1 |
| IRFP260 | Q1 (no instale esto todavía) |
| Interruptor | |
| Conector de alimentación DC5525 negro| | 
| Potenciómetro B1K simple| |

- Se recomienda soldar primero los componentes más cortos, luego los componentes más altos, como soldar primero los condensadores SMD, resistencias, reguladores de voltaje, bloques de terminales, etc., y finalmente soldar los condensadores electrolíticos y el interruptor. Si no tiene experiencia en soldadura, asegúrese de buscar tutoriales de soldadura en Bilibili para aprender primero. Según estadísticas históricas, el 60% de las personas que tuvieron problemas después de fabricarlo se debió a un mal contacto entre los componentes y el PCB causado por no dominar el método de soldadura correcto.
  
  > Identificación de resistencias
  > - La resistencia de 1k tiene una línea marrón   
  > - La resistencia de 1.8k tiene una línea marrón y una línea gris
  > - La resistencia de 3k tiene una línea naranja
  > Si realmente no puede distinguirlas, simplemente mida con un multímetro ^_^

  > Identificación de condensadores
  > - Los condensadores de 4.7nF son relativamente más delgados
  > - Los condensadores de 220pF/100pF son relativamente más gruesos
  > - Para los condensadores resonantes, puede elegir dos de 220pF o cuatro de 100pF
  
  > Identificación de la dirección del diodo
  > - El TVS negro no es direccional
  > - El diodo regulador de voltaje rojo debe ser direccional, la línea negra en el diodo regulador de voltaje debe coincidir con la posición de la línea blanca en la serigrafía del PCB.

  > Puede que algunos amigos no sepan soldar componentes SMD, puedes buscar tutoriales de soldadura de componentes SMD en Youtube para aprender. En pocas palabras, soldar primero un lado para fijar el componente SMD y luego soldar el otro lado.
  
  > 【Cómo soldar SMD correctamente - Parte 1 / Tutorial de soldadura SMD - Youtube】 https://www.youtube.com/watch?v=EW9Y8rDm4kE

  > Asegúrese de prestar atención a la dirección del condensador electrolítico, soldarlo al revés puede causar un calentamiento intenso o incluso una explosión. La pata más larga del condensador electrolítico es el electrodo positivo y el lado con la marca de la raya es el electrodo negativo. Consulte la siguiente imagen para instalar correctamente el condensador electrolítico.



- Cuando suelde, **tenga cuidado con la alta temperatura del soldador para evitar quemaduras.**

- Después de soldar todos los componentes, corte las patillas. Intente asegurarse de que las juntas de soldadura estén llenas y sean suaves, y comience desde la raíz al quitar las patillas.

 

- Atornille columnas de cobre de 6 mm (o columnas de nylon de 6 mm) en los orificios para tornillos alrededor del disipador de calor.



- Instale el MOSFET. Coloque el lado del MOSFET con texto **hacia arriba**, acolche el otro lado con una almohadilla de silicona y fíjelo en el disipador de calor con tornillos, con las patillas **hacia abajo**. En este momento, las patillas de izquierda a derecha son los polos G, D y S respectivamente.





- Doble las patillas e insértelas en el PCB. **Primero alinee los orificios del PCB y el disipador de calor para asegurarse de que los cuatro tornillos se puedan apretar**, luego suelde el MOSFET.



- Fije el ventilador. La conexión de todas las capas se muestra en la figura a continuación. El flujo de aire del ventilador sopla hacia el disipador de calor (soplando hacia arriba).







- Use tornillos para montar el soporte de la bobina en la parte superior, con los dos cables orientados hacia el bloque de terminales verde de la bobina.




- Corte el cable esmaltado adecuadamente para que se pueda insertar en el bloque de terminales.
- Use un cuchillo multiusos para raspar el esmalte en el extremo del cable para exponer el núcleo de cobre dentro del cable esmaltado.
- **Nota: ¡Asegúrese de raspar bien el esmalte en el extremo del cable, de lo contrario, un contacto deficiente puede impedir que funcione!**



- Inserte los dos cables de la bobina en los pines 1 y 3 del bloque de terminales verde (el orificio del medio no se usa) e inserte el cable de alimentación del ventilador en la interfaz del ventilador en la parte posterior del PCB.

- Después de confirmar nuevamente que todas las piezas están conectadas correctamente, puede prepararse para encender o(*￣▽￣*)ブ

- Si está utilizando una fuente de alimentación ajustable, utilice el modo de limitación de corriente (CC), ajuste el voltaje de salida a 24 V y el límite de corriente a 3,5 A.
- Coloque la botella y asegúrese de que el potenciómetro esté en la posición máxima en sentido antihorario.

- Antes de encender, lea atentamente las instrucciones de seguridad:
  > Manténgase alejado de la bobina cuando el circuito esté funcionando, ya que la alta temperatura de la bobina puede causar quemaduras.
  
  > Puede girar la botella, pero la botella también se calentará. Tenga cuidado y mantenga las manos alejadas de la bobina (al menos a 1 cm de distancia) al girar la botella.
  
  > Puede girar el potenciómetro mientras el circuito esté funcionando, pero no sostenga la botella con una mano y toque el potenciómetro en el circuito con la otra mano, porque la electricidad estática de alto voltaje en la botella puede dañar el circuito.
  
  > El circuito se calentará. No se recomienda hacer funcionar el circuito durante mucho tiempo. Se recomienda trabajar continuamente durante no más de dos minutos.

  > Después del uso, recuerde apagar el interruptor y desconectar la fuente de alimentación.

- Después de asegurarse de que ha leído las instrucciones de seguridad, enchufe la fuente de alimentación y encienda el interruptor. En este momento, el ventilador debería comenzar a girar.

- Gire el potenciómetro en sentido horario. Cuando se gira aproximadamente hasta la mitad, el circuito comenzará a funcionar. Cuando el circuito comienza a funcionar, el LED junto a la bobina se encenderá. En este punto, use un encendedor para apuntar a la botella y haga clic en él para generar el toroide. Si el encendedor no logra generar el toroide, puede girar el potenciómetro un poco más en sentido horario y volver a intentarlo.





- A veces, su botella puede brillar en blanco sin generar un toroide (como se muestra a continuación). Ajustar la posición de la botella y volver a encenderla algunas veces generalmente lo soluciona.



- Después de generar el toroide, girar ligeramente el potenciómetro provocará algunos cambios en la forma del toroide. Si el toroide desaparece, volver a encenderlo lo generará nuevamente.



### Diagrama de circuito de referencia
Dado que el hardware de este proyecto aún se está actualizando, el diagrama del circuito es solo de referencia. El circuito real debe basarse en el PCB.



### Preguntas frecuentes
Si tiene alguna pregunta, únase al grupo de telegram: 
https://t.me/+eRFEajIG6_RiMTY1.



Todos los desarrolladores del proyecto están en el grupo y puede obtener respuestas a la velocidad más rápida. (Intentamos responder todas sus preguntas dentro de las 24 horas).

#### Agradecimientos:
Tate McAluney

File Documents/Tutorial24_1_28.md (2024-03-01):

# 等离子环制作说明

此文档更新于2024年1月28日

作者 *对角巷魔法商店*

[成品效果视频](https://www.bilibili.com/video/BV1YQ4y157gs)

[立创开源平台](https://oshwhub.com/skylake/plasmatoroid-drive-circuit)

等离子环开源技术交流QQ群  736688139

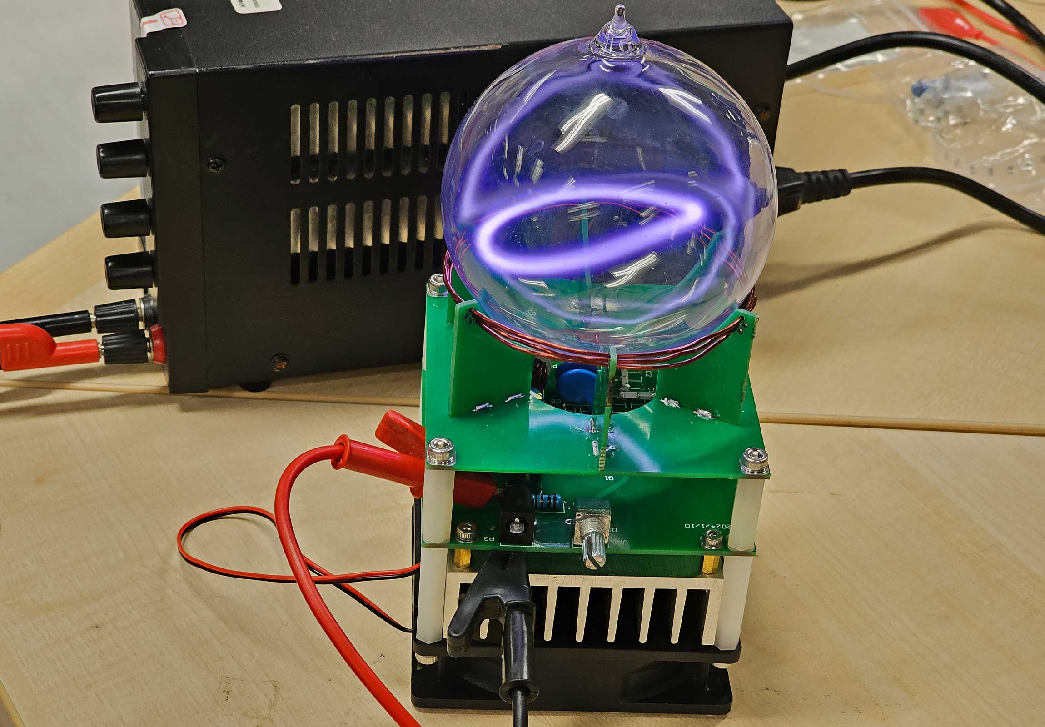
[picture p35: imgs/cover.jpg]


## 版权声明©

此文档仅供个人学习制作等离子环使用，未经作者同意，任何人不得修改、重新发布、发行本文档内容。严禁使用本文档进行任何商业行为。

## 免责声明
在您使用本文档制作等离子环前，请仔细阅读以下重要安全警告和免责说明。使用本文档即表示您已充分了解并同意以下条款：
- 等离子环的危险性：等离子环在运行时玻璃瓶身会产生高温，存在低温烧伤风险。任何时候都不建议用手直接触摸正在运行的玻璃瓶，以免烧伤。
- 磁场警告：等离子环在运行时会产生较强磁场。对于佩戴心脏起搏器及其他医疗设备的人群，强磁场可能会影响设备正常工作。我们建议这部分用户应远离正在工作的等离子环，避免可能的健康风险。
- 高电压风险：等离子环的驱动电路在工作时会产生高电压。高电压存在触电或灼伤的危险，请在电路工作时不要触碰任何元件，包括初级线圈，以免触电或烧伤。
- 元件温度：请注意，电路的某些元件在运行时可能会变得非常热，这可能会造成烫伤。请在设备运行时，特别是长时间运行后，不要触摸这些元件。
- 电磁干扰：等离子环运行时会发射10MHz左右的电磁波，该波段对人体无伤害，但可能干扰此频段运行的部分电子设备，例如触摸板和刷卡机，请将这些设备远离正在工作的驱动电路。

使用本文档意味着您已经了解并同意自担使用风险，对于不遵守安全指南而造成的任何直接或间接损害，作者不承担任何责任。

谨慎DIY，安全至上！

## 等离子环（Plasma Toroid）的工作原理解析

  - 辉光放电现象：在特定条件下，气体会在强电场的作用下发生辉光放电。这一过程中，气体分子的电子受激发后跃迁至更高能级轨道。由于这些电子在高能态下并不稳定，它们会自主回落至原始低能轨道，同时根据能量守恒定律释放出能量差对应的光子。这一现象就是辉光放电，它被应用于霓虹灯等装置中。等离子环的发光过程与此类似。

  - 等离子体的性质：除了常见的固体、液体和气态，等离子体是存在于宇宙中的另一种物质状态，火焰便是包含等离子体的例子。当气体受到高温的影响时，分子间的碰撞会使得外层电子脱离其轨道，形成一种由带电粒子组成的等离子体。这种带电的离子混合物具有导电性。
  - 环形电磁场的产生：通过在环形线圈中通入高频交变电流，可以根据麦克斯韦方程组得出其周围电场分布为环形。我们使用自激的Class E震荡电路来生成频率为10MHz左右的交流电。

  - 等离子环的生成过程：在一个封有低压氙气的球形玻璃瓶内，氙气在强电场的作用下被电离，形成等离子体。这些导电的氙气等离子体在外加环形电场的影响下，形成稳定的环状结构。在等离子体中，带电粒子的碰撞产生辉光放电，进而发出淡紫色的光芒，这使得等离子环可见。

**请您在使用和展示等离子环时，确保理解其工作原理和相应的安全措施，以保障使用者的安全。**

## 准备材料

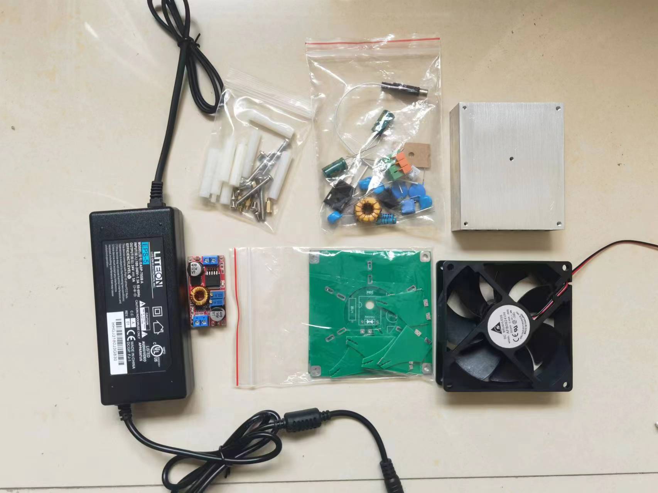
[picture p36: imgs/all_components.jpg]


- 充有氙气的玻璃瓶80mm(在淘宝搜索等离子环可找到,更大的玻璃球无法安装到本项目的支架中)
- 漆包线 —— 绕线电感 （作者使用的漆包线都是1.2mm的）
- 漆包线 —— 初级线圈
- 电路板PCB (可用洞洞板或者搭棚替代)
- 散热片与风扇
- MOS管 IRFP260N
- 电位器 10k（最好是蓝色的多圈电位器）
- 电阻470（在新版本中这个电阻被换为了1k）
- 电阻1k
- 瓷片电容 30pf * 4
- 瓷片电容 4.7nF * 2
- TVS 15V （双向）
- 稳压二极管 12V
- 输入滤波电容 电解电容 63V 220uf * 3 
- 接线端子
- 打火机中拆出来的压电陶瓷 (用于初始点亮)
- 24v电源适配器
- XL4015限流模块

## 制作教程
难度 ★★★☆☆

### 工具
- 万用表 
- 电烙铁 
- 焊锡丝 
- 小刀 
- 斜口钳 
- 内六方螺丝刀套装



### 步骤
- 烧热烙铁，准备好六个初级线圈架，插在底座上，用焊锡焊接固定。尽可能保证支架和底板处于垂直状态。
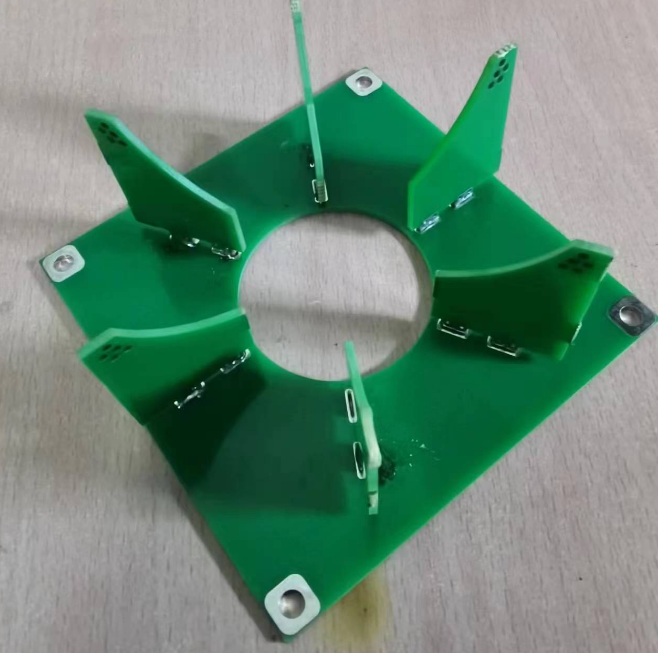
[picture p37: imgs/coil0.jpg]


- 把漆包线按照线圈架的直径弯曲三圈后剪短

- 把截下的漆包线留出约一指长作为接头拉出备用，按照小孔从上到下穿入，共三圈。穿好后另一头用同样方式拉出。孔位较小，可以通过推拉的方式穿入。

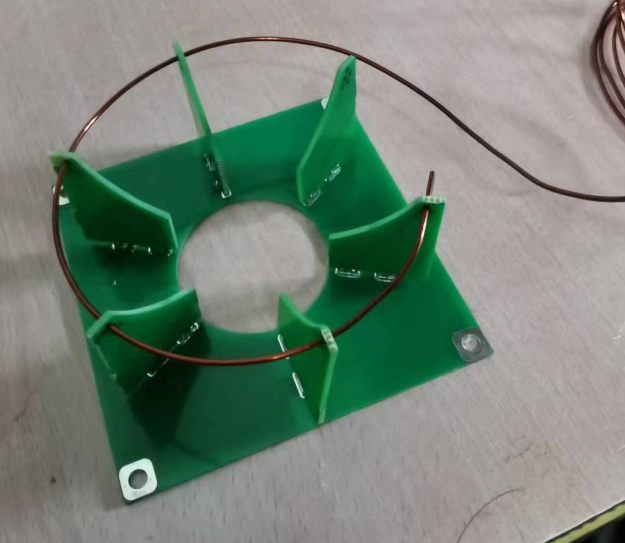
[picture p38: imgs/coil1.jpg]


- 用小刀刮开线头漆皮，露出漆包线内部的铜芯。用烙铁和焊锡为铜芯镀锡
  
- 制作扼流电感。取出较长的漆包线，绕成直径大概25mm的线圈，绕20圈即可，最后用尼龙扎带固定住线圈。扼流电感也可以使用现成的10uH电感，但发热比手绕电感大一些。

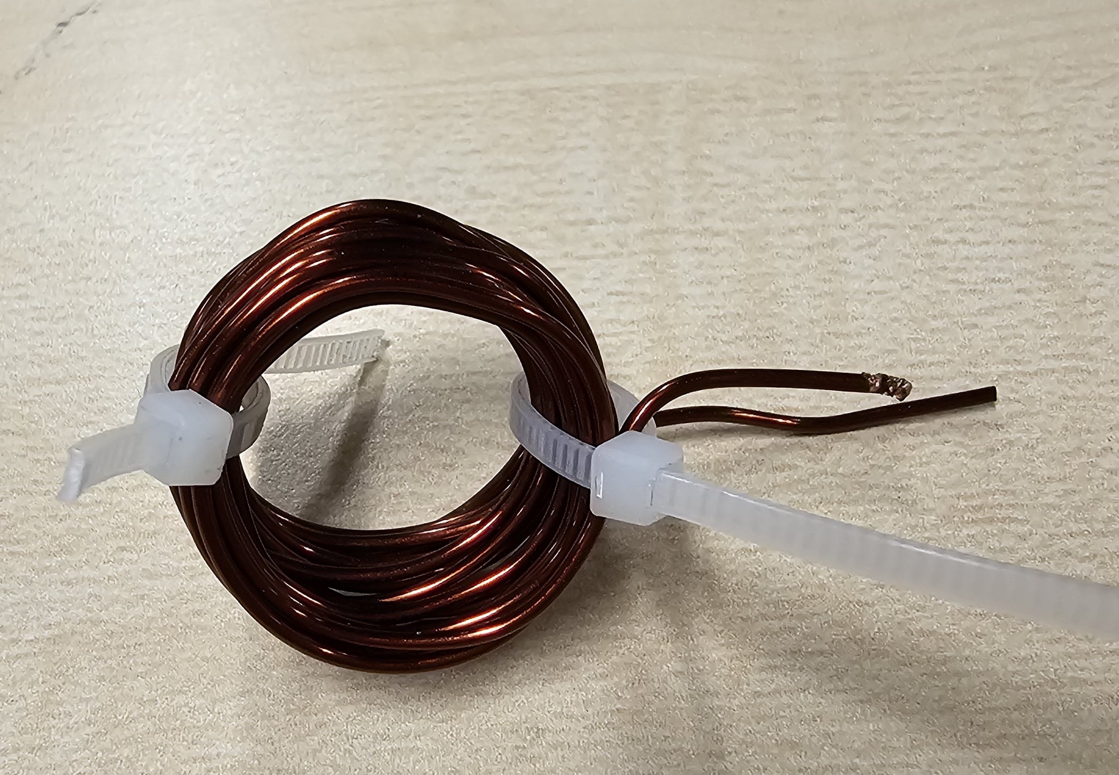
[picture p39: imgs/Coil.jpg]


- 制作带限流保护的电源，准备好24V电源和XL4015限流模块，将电源线剪开，把模块串联在中间，将XL4015模块调输出电压的电位器顺时针拧到头，将限流电位器拧到3.5A的位置，确定该电位器位置的方法是:将万用表打到10A电流档，两个表笔对到输出上（此时相当于短路了输出），万用表显示的数值就是限流模块的限流值。注意，使用没有限流的电源会十分容易烧毁mos管，如果已经有可调电源则可以跳过这一步。下图中模块左边的电位器是调节输出电压，右边的电位器是调节限流。



- 将元件按照型号分别插入电路板 (先不要安装MOS管)，由于电路在持续更新，实际电路板上的元件以最新版为准。
  
  > 电阻分辨方式
  >  - 色环电阻上带有紫色环的为470电阻(470电阻也可换为1k电阻)
  >	 - 只有棕色和黑色环的为1K电阻

  > 电容分辨方式
  > 蓝色电容上有数字说明其属性
  > - 30pF电容正面有300K字样
  > - 4.7nF电容正面有472字样

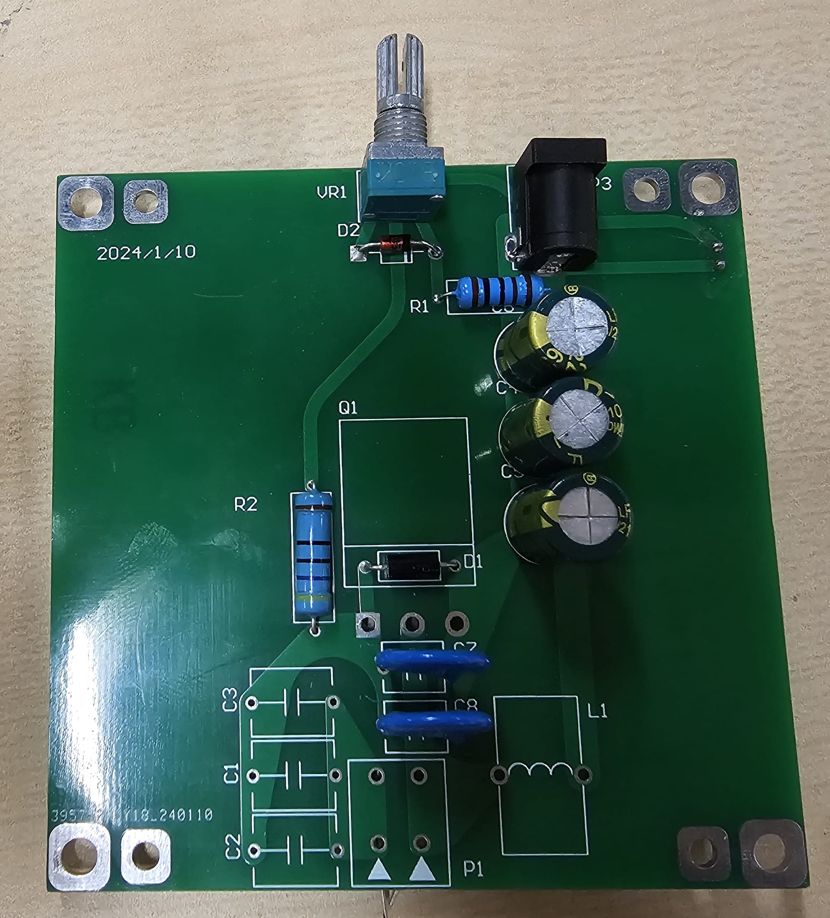
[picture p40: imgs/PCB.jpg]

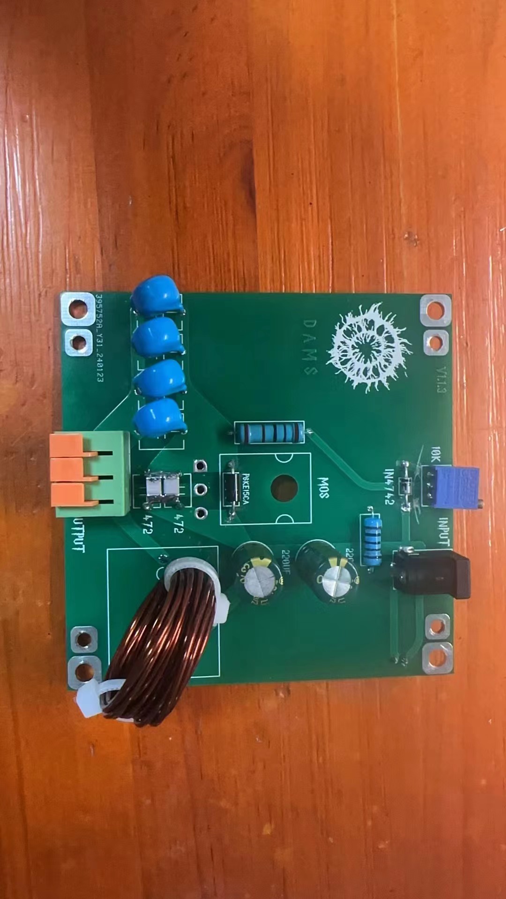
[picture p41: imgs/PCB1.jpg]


- 将元件按照其属性分别放入PCB上等待焊接。为了方便焊接，可以将管脚进行简单折弯固定。
- 开始焊接，**注意烙铁高温，小心烫伤。**

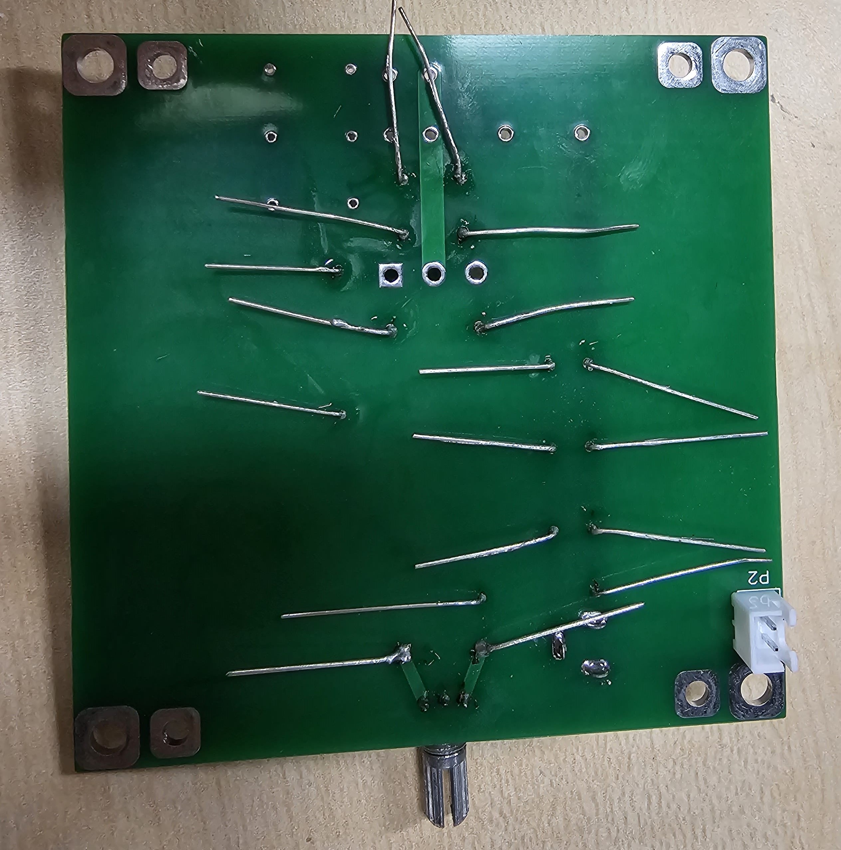
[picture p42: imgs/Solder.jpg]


- 将所有元件焊接好后，剪去管脚。请尽量保证焊点饱满圆润，去除管脚时请从根部开始。

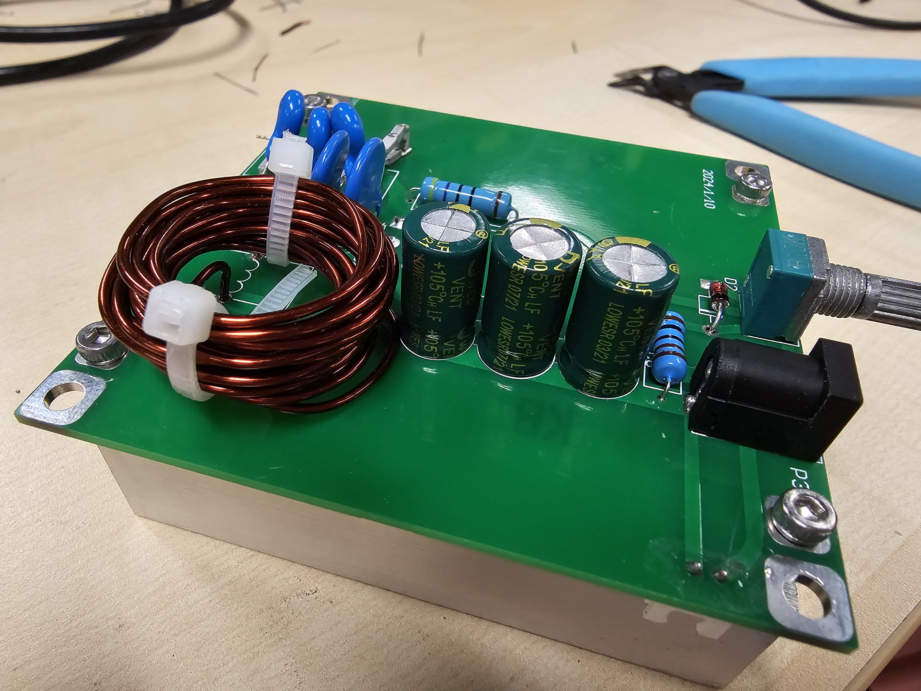
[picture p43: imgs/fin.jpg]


- 将散热片四周螺丝孔内拧入铜柱。
- 开始安装MOSFET。将MOS管有字的一面***向上***，将另一面涂上硅脂后用螺丝穿过螺丝孔固定在散热片上，MOS有字的一面面对自己，管脚***向下***，此时管脚左中右分别为G D S极。

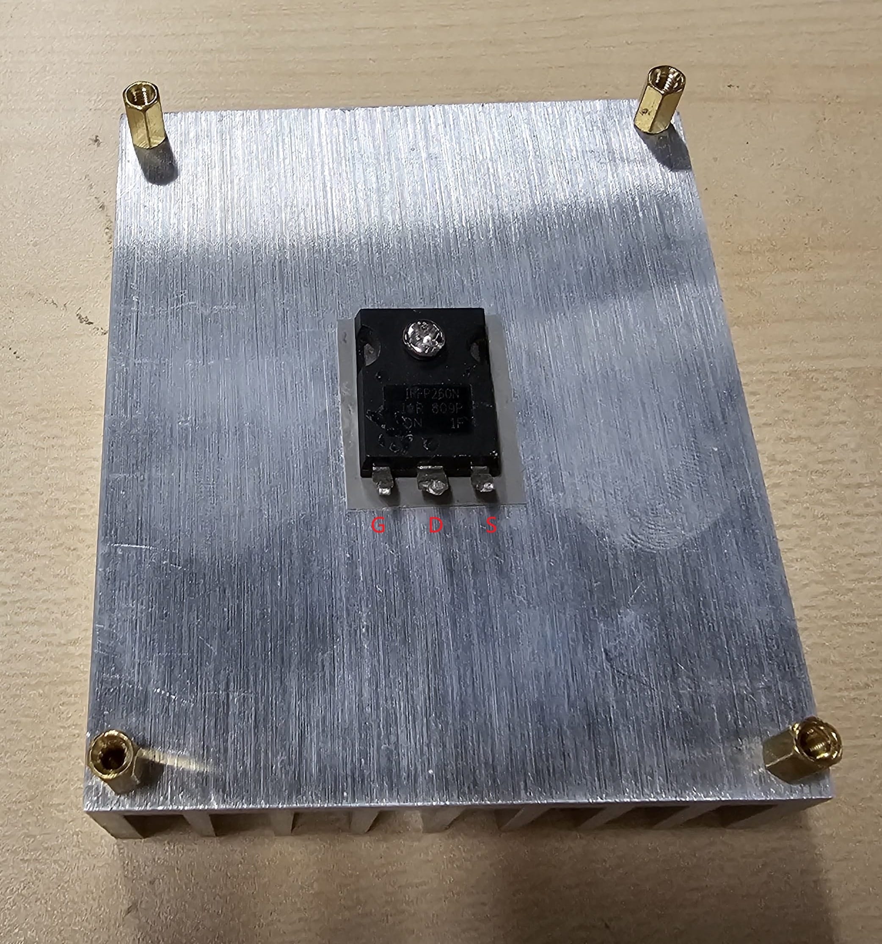
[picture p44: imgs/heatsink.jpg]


- 将管脚弯曲后插入PCB焊接。
**注意：弯曲时请勿从管脚根部开始，应当从小节开始**
- 将PCB对准散热片铜柱螺丝孔，用新的铜柱固定。
- 固定风扇,所有层的连接关系如下图所示，风扇的风冲着散热片吹（朝上吹）。

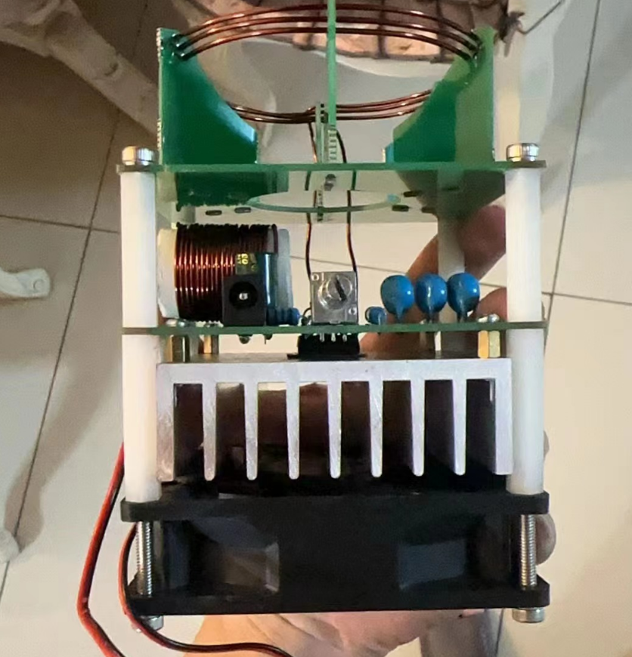
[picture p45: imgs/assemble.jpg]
  
  
- 将所有电路连接好，放上瓶子，并确保电位器位于逆时针最大处
- 通电，请注意安全！手远离初级线圈附近。千万不要一个手拿着瓶子一个手触摸电路上的电位器，因为瓶子上的高压静电会损坏电路。
- 慢慢向顺时针拧电位器，拧到一半的时候即可看到等离子环生成，此时再逆时针轻轻拧动，保持等离子环稳定即可。有的时候可能不会自启动，只需要用压电陶瓷打一下电火花即可出环。
- **注意：顺时针拧电位器会增大功率，长时间大功率运转会烧坏电路，建议把电位器保持在等离子环刚好不消失的位置！使用完后一定要拔掉电源！**

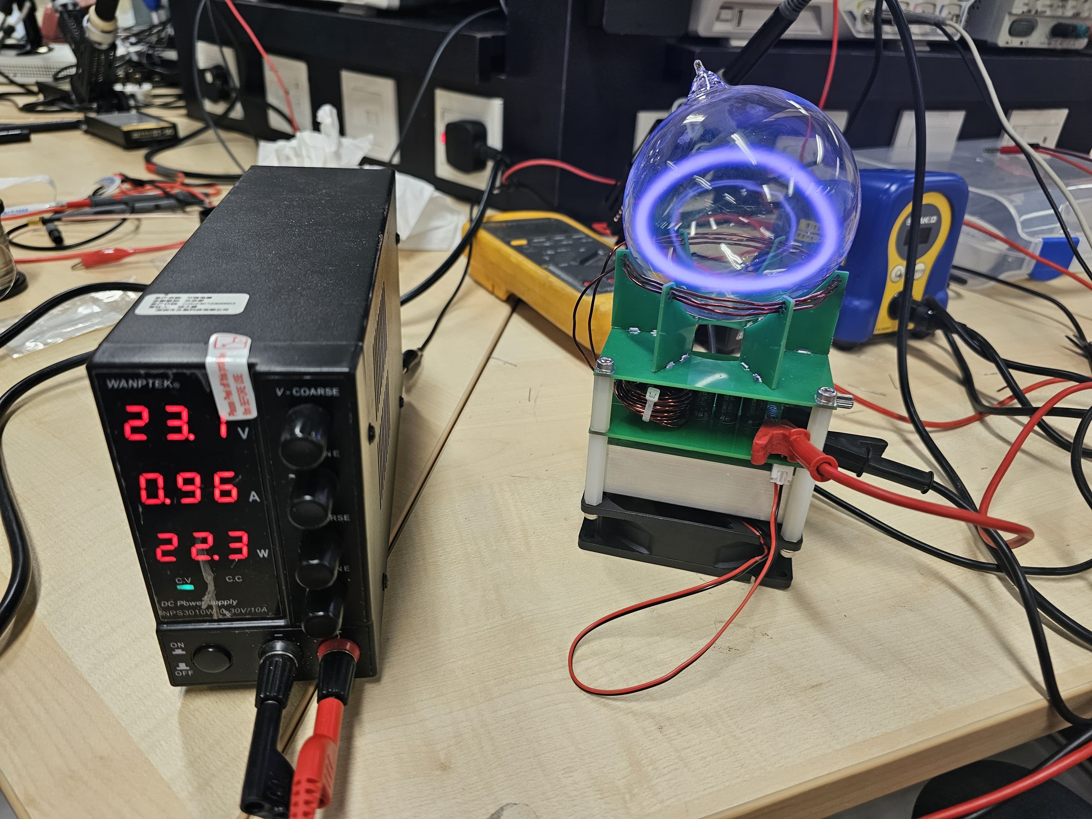
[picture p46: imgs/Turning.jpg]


### 参考电路图
注意，此电路图仅供参考，实际电路和元件参数我们做了调整，以元件清单中的为准。



### FAQ

鸣谢： Tate McAluney

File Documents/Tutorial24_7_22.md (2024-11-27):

# 等离子环制作说明

此文档更新于2024年7月22日

作者 *对角巷魔法商店*

本文中所使用的零件均可在淘宝店铺***对角巷魔法商店***找到，全套电路零件只要99元

[成品效果视频1](https://www.bilibili.com/video/BV1Lm411z7tf)

[成品效果视频2](https://www.bilibili.com/video/BV12f421o7rf)

[立创开源平台](https://oshwhub.com/skylake/plasmatoroid-drive-circuit)

等离子环开源技术交流QQ群  736688139



## 版权声明©

此文档仅供个人学习制作等离子环使用，未经作者同意，任何人不得修改、重新发布、发行本文档内容。严禁使用本文档进行任何商业行为。

## 免责声明
在您使用本文档制作等离子环前，请仔细阅读以下重要安全警告和免责说明。使用本文档即表示您已充分了解并同意以下条款：
- 等离子环的危险性：等离子环在运行时玻璃瓶身会产生高温，存在低温烧伤风险。任何时候都不建议用手直接触摸正在运行的玻璃瓶，以免烧伤。
- 磁场警告：等离子环在运行时会产生较强磁场。对于佩戴心脏起搏器及其他医疗设备的人群，强磁场可能会影响设备正常工作。我们建议这部分用户应远离正在工作的等离子环，避免可能的健康风险。
- 高电压风险：等离子环的驱动电路在工作时会产生高电压。高电压存在触电或灼伤的危险，请在电路工作时不要触碰任何元件，包括初级线圈，以免触电或烧伤。
- 元件温度：请注意，电路的某些元件在运行时可能会变得非常热，这可能会造成烫伤。请在设备运行时，特别是长时间运行后，不要触摸这些元件。
- 电磁干扰：等离子环运行时会发射10MHz左右的电磁波，该波段对人体无伤害，但可能干扰此频段运行的部分电子设备，例如触摸板和刷卡机，请将这些设备远离正在工作的驱动电路。

使用本文档意味着您已经了解并同意自担使用风险，对于不遵守安全指南而造成的任何直接或间接损害，作者不承担任何责任。

谨慎DIY，安全至上！

## 等离子环（Plasma Toroid）的工作原理解析

  - 辉光放电现象：在特定条件下，气体会在强电场的作用下发生辉光放电。这一过程中，气体分子的电子受激发后跃迁至更高能级轨道。由于这些电子在高能态下并不稳定，它们会自主回落至原始低能轨道，同时根据能量守恒定律释放出能量差对应的光子。这一现象就是辉光放电，它被应用于霓虹灯等装置中。等离子环的发光过程与此类似。

  - 等离子体的性质：除了常见的固体、液体和气态，等离子体是存在于宇宙中的另一种物质状态，火焰便是包含等离子体的例子。当气体受到高温的影响时，分子间的碰撞会使得外层电子脱离其轨道，形成一种由带电粒子组成的等离子体。这种带电的离子混合物具有导电性。
  - 环形电磁场的产生：通过在环形线圈中通入高频交变电流，可以根据麦克斯韦方程组得出其周围电场分布为环形。我们使用自激的Class E震荡电路来生成频率为10MHz左右的交流电。

  - 等离子环的生成过程：在一个封有低压氙气的球形玻璃瓶内，氙气在强电场的作用下被电离，形成等离子体。这些导电的氙气等离子体在外加环形电场的影响下，形成稳定的环状结构。在等离子体中，带电粒子的碰撞产生辉光放电，进而发出淡紫色的光芒，这使得等离子环可见。

**请您在使用和展示等离子环时，确保理解其工作原理和相应的安全措施，以保障使用者的安全。**

## 准备材料

 

- 充有氙气的玻璃瓶80mm(在淘宝**对角巷魔法商店**可找到,更大的玻璃球无法安装到本项目的支架中)
- 1.2mm 漆包线 —— 绕制线圈
- 黑环电感 10uH
- 电路板PCB (可使用hardware文件夹中的文件制作)
- 线圈支架，包括底板和五片支架
- 散热片与风扇
- MOS管 IRFP260N
- MOS管散热硅胶垫
- 电位器 1k
- 电阻1k * 3
- 电阻1.8k, 3k
- 贴片电容 100pf * 4
- 贴片电容 4.7nF * 2
- TVS 15V P6KE15CA
- 稳压二极管 9.1V
- 输入滤波电容 电解电容 63V 220uf
- 钮子开关
- 绿色接线端子 —— 用于接线圈
- 白色风扇插座
- DC电源接口
- 发光二极管
- 螺丝与尼龙柱
- 打火机中拆出来的压电陶瓷 (用于初始点亮)
- XL4015限流模块 （有可调电源可以不准备此模块）
- 24v电源适配器（4A以上，或者有可调电源也可）

## 制作教程
难度 ★★★☆☆

### 工具
- 万用表 
- 电烙铁 
- 焊锡丝 
- 小刀 
- 斜口钳 
- 内六方螺丝刀套装
- 镊子（用于焊接贴片电容）



### 步骤
- 准备好五个线圈支架，插在底座上，烧热烙铁，用焊锡焊接固定。尽可能保证支架和底板处于垂直状态。（五片线圈支架要用一些力才能塞进去）

 

- 把漆包线按照线圈架的直径弯曲，不要拉直漆包线，保持漆包线弯曲有助于穿线，一旦拉直就穿不进去了。



- 将漆包线按照小孔从上到下穿入，共四圈。孔位较小，可以通过推拉的方式穿入。





- 制作带限流保护的电源（已有可调电源的话可以跳过此步），准备好24V电源和XL4015限流模块，将电源线剪开，把模块串联在中间，将XL4015模块调输出电压的电位器顺时针拧到头(拧到头会有咔哒响声)，将限流电位器拧到3.5A的位置，确定该限流电位器位置的方法是:将万用表打到10A电流档，表笔插入10A的孔位，两个表笔对到输出上（此时相当于短路了输出，可能有电火花但没事），万用表显示的数值就是限流模块的限流值。注意，使用没有限流的电源会十分容易烧毁mos管，一定要串联XL4015模块再接电。如果已经有可调电源则可以跳过这一步。下图中模块左边的电位器是调节输出电压，右边的电位器是调节限流，顺时针拧增大。
- 如果您是使用可调电源，请使用限流模式（CC）,设置输出电压24V，限流3.5A。




- 将元件按照型号分别插入电路板 (先不要安装MOS管)，为了方便焊接，可以将管脚进行简单折弯固定。注意，**风扇的接线座应该安装在PCB背面，在线圈支架PCB上还需要焊接一个发光二极管和1k电阻**。
各元件安装位置如下表所示。

| 元件名称 | 安装位置 |
|---|---|
| 1k电阻 * 3 | R1, R4, 线圈支架PCB |
| 发光二极管 | 线圈支架PCB |
| 3k电阻 | R2 |
| 1.8k电阻 | R3 |
| 稳压二极管 | D2 |
| TVS（黑色） | D1 |
| 绿色接线座 | P1 |
| 白色接线座 | P3（安装在背面）|
| 220uf电解电容 | C5 |
| 100pf电容 * 4 | C1, C2, C3, C4  |
| 4.7nf电容 * 2 | C6, C7 |
| 10uH电感 | L1 |
| IRFP260 | Q1 (这个先不安装) |
| 开关 | |
| DC5525黑色电源插座 | |
| B1K单联电位器 | |

- 建议先焊接矮的元件，再焊接高的元件，例如先焊接贴片电容，电阻，稳压管，接线座等，最后焊接电解电容，开关。如果没有焊接经验，务必先在B站搜索焊接教程学习一下。经过历史统计，制作完后出现问题的人中有60%是因为没有掌握正确的焊接方法导致了元件和PCB接触不良。
  
  > 电阻分辨方式
  >  - 1k电阻上有个棕色线
  >	 - 1.8k电阻上有棕色线和灰色线
  >	 - 3k电阻上有橙色线
  >	 实在分辨不明白就用万用表量吧^_^

  > 电容分辨方式
  >  - 4.7nF电容相对薄一些
  >	 - 220pF/100pF电容相对厚一些
  >  - 谐振电容可以选择220pF两个或100pF四个

  > 二极管方向分辨方式
  >  - 黑色的TVS不分方向
  >	 - 红色的稳压二极管需要分方向，稳压二极管上的黑线对准PCB上面丝印中的白线位置。

  > 部分朋友可能不会焊接贴片元件，可以在B站搜索贴片元件焊接教程学习下。简单说来，先焊上一边固定住贴片元件，再焊接另一边。
  >【两脚的贴片元件如何快速焊接？有哪些注意事项？几分钟就掌握技巧-哔哩哔哩】 https://b23.tv/XZ3q8Bh

  > 务必注意电解电容的方向，焊反可能会剧烈发热甚至爆炸。电解电容脚长的一边是正极，有条纹标记的一边是负极。请参考下图正确安装电解电容。



- 焊接时，**注意烙铁高温，小心烫伤。**

- 将所有元件焊接好后，剪去管脚。请尽量保证焊点饱满圆润，去除管脚时请从根部开始。



- 将散热片四周螺丝孔内拧入6mm铜柱(或者6mm尼龙柱)。



- 安装MOSFET。将MOS管有字的一面**向上**，将另一面垫上硅胶垫后用螺丝固定在散热片上，管脚**对着下方**，此时管脚左中右分别为G D S极。





- 将管脚弯曲后插入PCB，**先将PCB和散热片孔位对准，确保能拧上四个螺丝**，随后再焊接MOS管



- 固定风扇,所有层的连接关系如下图所示，风扇的风冲着散热片吹（朝上吹）。







- 将线圈支架用螺丝安装到顶部，两根线对着绿色的线圈接线座




- 适当地剪短漆包线，使其能插入接线座即可。
- 用小刀刮开线头漆皮，露出漆包线内部的铜芯。
- **注意：一定要把线头漆皮刮干净，否则可能接触不良无法工作！**



- 将线圈的两根线插入绿色接线座的1,3引脚（中间的孔不插），将风扇电源线插入PCB背面的风扇接口。

- 再次确认所有部分连接正常后，就可以准备通电了o(*￣▽￣*)ブ

- 如果您是使用可调电源，请使用限流模式（CC）,设置输出电压24V，限流3.5A。
- 放上瓶子，并确保电位器位于逆时针最大处。

- 在通电之前，请仔细阅读安全说明：
  >  电路工作的时候一定要远离线圈，线圈的高温可能使人烫伤。

  >  可以转动瓶子，但瓶子也会发热，注意安全，转动瓶子时手远离线圈（至少距离1cm以上）。

  >	 可以在电路工作时拧电位器，但不要一个手拿着瓶子一个手触摸电路上的电位器，因为瓶子上的高压静电会损坏电路。

  >	 电路会发热，不建议长时间运行电路，建议连续工作不超过两分钟。

  >	 使用完毕后，记得关掉开关，断开电源。

- 确保阅读了安全说明后，插上电源，打开开关，此时应该风扇会转。

- 向顺时针拧电位器，大概拧到一半位置时，电路就会开始工作。电路开始工作后，线圈旁边的LED会亮起。此时使用点火器对准瓶子点一下即可出环。如果点火器点不出环，可以把电位器再顺时针拧大一些再点。
  




- 有时候，您的瓶子会泛白光而不出环（如下图所示），调整瓶子位置后重新点火几次一般就好了。


- 出环后，微微拧动电位器环的形态会发生一些变化，如果环消失了，重新点火即可再次出环。



### 参考电路图
由于此项目的硬件还在不断更新，电路图仅供参考，实际以PCB为准


### FAQ
如果有任何问题，加QQ群 736688139，所有项目开发人员都在群中，您可以以最快的速度获得答案。

鸣谢： Tate McAluney

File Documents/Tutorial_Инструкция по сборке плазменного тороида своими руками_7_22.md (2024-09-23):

# Инструкция по сборке плазменного тороида своими руками

Этот документ был обновлен 22 июля 2024 года.

Автор: *Магазин Диагон-аллеи*

Все компоненты, используемые в этом документе, можно найти в магазине Aliexpress ***Магазин Диагон-аллеи***. 

[Принцип работы плазменного тороида](https://www.youtube.com/watch?v=GbMAvn7nRWo)

[Демонстрационное видео готового продукта 1](https://www.bilibili.com/video/BV1Lm411z7tf)

[Демонстрационное видео готового продукта 2](https://www.bilibili.com/video/BV12f421o7rf) 

[Открытая платформа LCEDA](https://oshwhub.com/skylake/plasmatoroid-drive-circuit)

Открытая технологическая группа Telegram по плазменным тороидам:
https://t.me/+eRFEajIG6_RiMTY1



## Уведомление об авторских правах©

Этот документ предназначен только для личного обучения и изготовления плазменных тороидов. Без согласия автора никто не может изменять, переиздавать или распространять содержание этого документа. Строго запрещается использовать этот документ для любых коммерческих целей.

## Отказ от ответственности
Прежде чем использовать этот документ для создания плазменного тороида, пожалуйста, внимательно прочитайте следующие важные предупреждения о безопасности и отказы от ответственности. Использование этого документа означает, что вы полностью понимаете и соглашаетесь со следующими условиями:
- Опасности плазменных тороидов: При работе плазменного тороида стеклянная бутылка будет нагреваться до высоких температур, существует риск низкотемпературных ожогов. Никогда не рекомендуется непосредственно касаться руками работающей стеклянной бутылки, чтобы избежать ожогов.
- Предупреждение о магнитном поле: Плазменный тороид будет генерировать сильное магнитное поле во время работы. Для людей с кардиостимуляторами и другими медицинскими устройствами сильные магнитные поля могут повлиять на нормальную работу устройств. Мы рекомендуем таким пользователям держаться подальше от работающих плазменных тороидов, чтобы избежать потенциальных рисков для здоровья.
- Опасность высокого напряжения: Схема управления плазменным тороидом будет генерировать высокое напряжение во время работы. Высокое напряжение представляет опасность поражения электрическим током или ожогов. Пожалуйста, не прикасайтесь к каким-либо компонентам, включая первичную катушку, когда схема работает, чтобы избежать поражения электрическим током или ожогов.
- Температура компонентов: Обратите внимание, что некоторые компоненты схемы могут сильно нагреваться во время работы, что может привести к ожогам. Когда устройство работает, особенно после продолжительной работы, не прикасайтесь к этим компонентам.
- Электромагнитные помехи: Плазменный тороид будет излучать электромагнитные волны около 10 МГц при работе. Этот диапазон не вредит человеческому телу, но может создавать помехи для некоторых электронных устройств, работающих в этом диапазоне, таких как сенсорные панели и устройства для чтения карт. Пожалуйста, держите эти устройства подальше от работающей схемы управления.

Использование этого документа означает, что вы понимаете и соглашаетесь нести риски использования. Автор не несет ответственности за любые прямые или косвенные убытки, вызванные несоблюдением правил техники безопасности.

Собирайте устройство с осторожностью, безопасность прежде всего!

## Анализ принципа работы плазменных тороидов

  - Явление тлеющего разряда: При определенных условиях газ будет подвергаться тлеющему разряду под действием сильного электрического поля. В этом процессе электроны газовых молекул стимулируются и переходят на орбиты с более высоким энергетическим уровнем. Поскольку эти электроны нестабильны в высокоэнергетическом состоянии, они самопроизвольно падают обратно на исходную низкоэнергетическую орбиту, высвобождая фотоны, соответствующие разности энергий, согласно закону сохранения энергии. Это явление называется тлеющим разрядом и применяется в таких устройствах, как неоновые лампы. Процесс свечения плазменных тороидов похож на это.

  - Свойства плазмы: Помимо обычных твердого, жидкого и газообразного состояний, плазма является еще одним состоянием вещества, существующим во Вселенной, а пламя - это пример, содержащий плазму. Когда газ подвергается воздействию высокой температуры, столкновения между молекулами заставляют внешние электроны покидать свои орбиты, образуя плазму, состоящую из заряженных частиц. Эта смесь заряженных ионов обладает электропроводностью.
  - Генерация тороидального электромагнитного поля: Пропуская высокочастотный переменный ток через тороидальную катушку, из уравнений Максвелла можно вывести, что распределение электрического поля вокруг нее имеет тороидальную форму. Мы используем автоколебательную схему класса E для генерации переменного тока с частотой около 10 МГц.

  - Процесс генерации плазменного тороида: В сферической стеклянной бутылке, заполненной низким давлением ксенона, газ ксенона ионизируется под действием сильного электрического поля, образуя плазму. Эти проводящие плазмы ксенонового газа образуют стабильную тороидальную структуру под влиянием внешнего тороидального электрического поля. В плазме столкновения заряженных частиц вызывают тлеющий разряд, который излучает бледно-фиолетовый свет, делая плазменный тороид видимым.

**При использовании и демонстрации плазменного тороида, пожалуйста, убедитесь, что вы понимаете его принцип работы и соответствующие меры безопасности, чтобы обеспечить безопасность пользователей.**

## Подготовка материалов

 

- Стеклянная бутылка 80мм, наполненная газом ксенон (доступна в магазине Aliexpress **Магазин Диагон-аллеи**, более крупные стеклянные шары не могут быть установлены в кронштейне этого проекта)
- 1.2мм эмалированная проволока - для намотки катушек 
- Черный кольцевой индуктор 10uH
- Печатная плата PCB (может быть изготовлена с использованием файлов в папке hardware)
- Поддержка катушки, включая основную плату и пять опорных деталей
- Радиатор и вентилятор  
- MOSFET IRFP260N
- Силиконовая прокладка радиатора MOSFET 
- Потенциометр 1k
- Резистор 1k * 3
- Резистор 1.8k, 3k 
- SMD конденсатор 100pf * 4
- SMD конденсатор 4.7nF * 2
- TVS 15V P6KE15CA
- Диод регулятора напряжения 9.1V 
- Входной конденсатор фильтра Электролитический конденсатор 63V 220uf
- Тумблер
- Зеленая клеммная колодка - для подключения катушки
- Белый разъем вентилятора 
- Разъем питания постоянного тока
- Светодиод
- Винты и нейлоновые стойки
- Пьезокерамика, извлеченная из зажигалки (для первоначального поджига)
- Модуль ограничения тока XL4015 (этот модуль не требуется, если у вас есть регулируемый источник питания)
- Адаптер питания 24В (4А или выше, или вы можете использовать регулируемый источник питания)

## Инструкция по изготовлению
Сложность ★★★☆☆

### Инструменты 
- Мультиметр
- Паяльник
- Припой
- Канцелярский нож
- Бокорезы
- Набор шестигранных отверток
- Пинцет (для пайки SMD-конденсаторов)



### Шаги
- Подготовьте пять кронштейнов катушки, вставьте их в основание, нагрейте паяльник и припаяйте их на место. Постарайтесь обеспечить перпендикулярность кронштейнов к основной плате. (Для установки пяти деталей кронштейна катушки требуется некоторое усилие)

 

- Согните эмалированный провод в соответствии с диаметром каркаса катушки, не выпрямляйте эмалированный провод, сохранение изгиба эмалированного провода помогает при нанизывании, выпрямленный провод нельзя нанизать.



- Пропустите эмалированный провод через маленькие отверстия сверху вниз, всего четыре оборота. Отверстия относительно небольшие, и нанизывание можно выполнить, толкая и потягивая.

 



- Сделайте источник питания с защитой от ограничения тока (этот шаг можно пропустить, если у вас уже есть регулируемый источник питания), подготовьте источник питания 24В и модуль ограничения тока XL4015, обрежьте шнур питания, подключите модуль последовательно в середине, поверните потенциометр для регулировки выходного напряжения модуля XL4015 по часовой стрелке до упора (при повороте до упора будет слышен щелчок), поверните потенциометр ограничения тока в положение 3.5А. Способ определения положения потенциометра ограничения тока: установите мультиметр в диапазон измерения тока 10А, вставьте щупы в отверстие 10А, прикоснитесь двумя щупами к выходу (в этот момент выход замкнут, могут быть электрические искры, но это нормально), значение, отображаемое на мультиметре, является значением ограничения тока модуля ограничения тока. Обратите внимание, что использование источника питания без ограничения по току может легко сжечь MOSFET, вы должны подключить модуль XL4015 последовательно перед подключением питания. Если у вас уже есть регулируемый источник питания, вы можете пропустить этот шаг. На картинке ниже потенциометр слева от модуля служит для регулировки выходного напряжения, а потенциометр справа - для регулировки ограничения тока. Поворот по часовой стрелке увеличивает значение.
- Если вы используете регулируемый источник питания, пожалуйста, используйте режим ограничения тока (CC), установите выходное напряжение на 24В, а ограничение тока на 3.5А.




- Вставьте компоненты в печатную плату в соответствии с их типом (пока не устанавливайте MOSFET). Для удобства пайки вы можете слегка согнуть контакты, чтобы зафиксировать их. Обратите внимание, что **разъем вентилятора должен быть установлен на обратной стороне PCB, а светодиод и резистор 1k также должны быть припаяны на PCB кронштейна катушки**.
Позиции установки каждого компонента показаны в таблице ниже.

| Название компонента | Позиция установки |
|---|---|
| 1k резистор * 3 | R1, R4, PCB кронштейна катушки |
| Светодиод | PCB кронштейна катушки |
| 3k резистор | R2 |
| 1.8k резистор | R3 |
| Диод регулятора напряжения| D2 |
| TVS (черный) | D1 |
| Зеленая клеммная колодка| P1 |
| Белая клеммная колодка | Q3 (установлен на обратной стороне) |
| 220uf электролитический конденсатор| C5 |
| 100pf конденсатор * 4  | C1, C2, C3, C4 |
| 4.7nf конденсатор * 2  | C6, C7 |
| 10uH индуктор | L1 |
| IRFP260 | Q1 (пока не устанавливайте)  |
| Тумблер | |
| Черный разъем питания DC5525| |
| Потенциометр B1K | |

- Рекомендуется сначала паять более короткие компоненты, затем более высокие компоненты, такие как пайка SMD конденсаторов, резисторов, стабилизаторов напряжения, клеммных колодок и т.д. в первую очередь, и в конце паять электролитические конденсаторы и переключатель. Если у вас нет опыта пайки, обязательно поищите учебные пособия по пайке на Bilibili, чтобы сначала научиться. По историческим статистическим данным, у 60% людей, которые имели проблемы после изготовления, это было вызвано плохим контактом между компонентами и PCB из-за того, что они не освоили правильный метод пайки.
  
  > Идентификация резисторов
  >  - 1k резистор имеет коричневую полосу 
  >	 - 1.8k резистор имеет коричневую и серую полосы
  >	 - 3k резистор имеет оранжевую полосу
  >	 Если вы действительно не можете отличить их друг от друга, просто измерьте мультиметром ^_^

  > Идентификация конденсаторов 
  >  - 4.7nF конденсаторы относительно тоньше
  >	 - 220pF/100pF конденсаторы относительно толще  
  >  - Для резонансных конденсаторов вы можете выбрать два 220pF или четыре 100pF

  > Идентификация направления диода
  >  - Черный TVS ненаправленный
  >	 - Красный диод-стабилизатор напряжения должен быть направленным, черная линия на диоде-стабилизаторе напряжения должна соответствовать положению белой линии на шелкографии PCB.

  > Некоторые друзья могут не знать, как паять SMD-компоненты, вы можете поискать учебные пособия по пайке SMD-компонентов на Youtube, чтобы научиться. Если говорить просто, сначала припаяйте одну сторону, чтобы зафиксировать SMD-компонент, затем припаяйте другую сторону.
  >【Как правильно паять SMD - Часть 1 /Учебник по пайке SMD - Youtube】 https://www.youtube.com/watch?v=EW9Y8rDm4kE

  > Обязательно обратите внимание на направление электролитического конденсатора, пайка его задом наперед может вызвать интенсивный нагрев или даже взрыв. Более длинная ножка электролитического конденсатора является положительным электродом, а сторона с полосатой меткой - отрицательным электродом. Пожалуйста, обратитесь к картинке ниже, чтобы правильно установить электролитический конденсатор.



- После пайки всех компонентов обрежьте контакты. Пожалуйста, старайтесь обеспечить, чтобы паяные соединения были полными и гладкими, и при удалении контактов начинайте от корня.



- Вкрутите медные стойки 6мм (или нейлоновые стойки 6мм) в отверстия с резьбой вокруг радиатора.



- Установите MOSFET. Разместите сторону MOSFET с текстом **лицевой стороной вверх**, проложите другую сторону силиконовой прокладкой и закрепите на радиаторе винтами, контакты должны быть **обращены вниз**. В этот момент контакты слева направо - это полюса G, D и S соответственно.





- Согните контакты и вставьте их в PCB. **Сначала совместите отверстия PCB и радиатора, чтобы убедиться, что четыре винта можно затянуть**, затем припаяйте MOSFET.



- Закрепите вентилятор. Соединение всех слоев показано на рисунке ниже. Поток воздуха вентилятора направлен в сторону радиатора (дует вверх).





- Используйте винты, чтобы прикрепить кронштейн катушки сверху, два провода должны быть обращены к зеленой клеммной колодке катушки.




- Обрежьте эмалированный провод соответствующим образом, чтобы его можно было вставить в клеммную колодку.
- Используйте канцелярский нож, чтобы соскрести эмаль на конце провода и обнажить медный сердечник внутри эмалированного провода.  
- **Примечание: Обязательно соскоблите эмаль на конце провода начисто, иначе плохой контакт может помешать работе!**



- Вставьте два провода катушки в контакты 1 и 3 зеленой клеммной колодки (среднее отверстие не используется), и вставьте шнур питания вентилятора в разъем вентилятора на задней стороне PCB.

- После того, как вы снова убедитесь, что все детали правильно подключены, вы можете приготовиться к включению питания o(*￣▽￣*)ブ

- Если вы используете регулируемый источник питания, пожалуйста, используйте режим ограничения тока (CC), установите выходное напряжение на 24В, а ограничение тока на 3.5А.
- Наденьте бутылку и убедитесь, что потенциометр находится в максимальном положении против часовой стрелки.

- Перед включением питания, пожалуйста, внимательно прочитайте инструкции по безопасности:
  >  Держитесь подальше от катушки, когда схема работает, так как высокая температура катушки может вызвать ожоги.

  >  Вы можете вращать бутылку, но бутылка также будет нагреваться. Будьте осторожны и держите руки подальше от катушки (не менее 1 см), когда вращаете бутылку.

  >	 Вы можете вращать потенциометр, пока схема работает, но не держите бутылку одной рукой и не касайтесь потенциометра на схеме другой рукой, потому что высокое напряжение статического электричества на бутылке может повредить схему.

  >	 Схема будет нагреваться. Не рекомендуется непрерывно запускать схему в течение длительного времени. Рекомендуется работать непрерывно не более двух минут.

  >	 После использования не забудьте выключить переключатель и отключить источник питания.

- После того, как вы убедитесь, что прочитали инструкции по технике безопасности, вставьте источник питания и включите переключатель. В этот момент вентилятор должен начать вращаться.

- Поверните потенциометр по часовой стрелке. Когда он повернут примерно наполовину, схема начнет работать. Когда схема начнет работать, загорится светодиод рядом с катушкой. В этот момент используйте зажигалку, направьте ее на бутылку и щелкните, чтобы создать тороид. Если зажигалка не может создать тороид, вы можете немного повернуть потенциометр по часовой стрелке и попробовать снова.
  



- Иногда ваша бутылка может светиться белым, не создавая тороида (как показано ниже). Регулировка положения бутылки и повторное возбуждение несколько раз обычно исправляет это.
  


- После того, как тороид сгенерирован, небольшое вращение потенциометра вызовет некоторые изменения формы тороида. Если тороид исчезнет, повторное возбуждение снова создаст его.



### Справочная принципиальная схема
Поскольку аппаратное обеспечение этого проекта все еще обновляется, принципиальная схема приведена только для справки. Фактическая схема должна основываться на PCB.


### FAQ
Если у вас есть какие-либо вопросы, присоединяйтесь к группе Telegram:
https://t.me/+eRFEajIG6_RiMTY1.



Все разработчики проекта находятся в группе, и вы можете получить ответы с максимальной скоростью. (Мы стараемся ответить на все ваши вопросы в течение 24 часов.)

#### Благодарности:
Tate McAluney

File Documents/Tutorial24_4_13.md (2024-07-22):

# 等离子环制作说明

此文档更新于2024年4月13日

作者 *对角巷魔法商店*

本文中所使用的零件均可在淘宝店铺***对角巷魔法商店***找到，全套电路零件只要99元

[成品效果视频1](https://www.bilibili.com/video/BV1Lm411z7tf)

[成品效果视频2](https://www.bilibili.com/video/BV12f421o7rf)

[立创开源平台](https://oshwhub.com/skylake/plasmatoroid-drive-circuit)

等离子环开源技术交流QQ群  736688139



## 版权声明©

此文档仅供个人学习制作等离子环使用，未经作者同意，任何人不得修改、重新发布、发行本文档内容。严禁使用本文档进行任何商业行为。

## 免责声明
在您使用本文档制作等离子环前，请仔细阅读以下重要安全警告和免责说明。使用本文档即表示您已充分了解并同意以下条款：
- 等离子环的危险性：等离子环在运行时玻璃瓶身会产生高温，存在低温烧伤风险。任何时候都不建议用手直接触摸正在运行的玻璃瓶，以免烧伤。
- 磁场警告：等离子环在运行时会产生较强磁场。对于佩戴心脏起搏器及其他医疗设备的人群，强磁场可能会影响设备正常工作。我们建议这部分用户应远离正在工作的等离子环，避免可能的健康风险。
- 高电压风险：等离子环的驱动电路在工作时会产生高电压。高电压存在触电或灼伤的危险，请在电路工作时不要触碰任何元件，包括初级线圈，以免触电或烧伤。
- 元件温度：请注意，电路的某些元件在运行时可能会变得非常热，这可能会造成烫伤。请在设备运行时，特别是长时间运行后，不要触摸这些元件。
- 电磁干扰：等离子环运行时会发射10MHz左右的电磁波，该波段对人体无伤害，但可能干扰此频段运行的部分电子设备，例如触摸板和刷卡机，请将这些设备远离正在工作的驱动电路。

使用本文档意味着您已经了解并同意自担使用风险，对于不遵守安全指南而造成的任何直接或间接损害，作者不承担任何责任。

谨慎DIY，安全至上！

## 等离子环（Plasma Toroid）的工作原理解析

  - 辉光放电现象：在特定条件下，气体会在强电场的作用下发生辉光放电。这一过程中，气体分子的电子受激发后跃迁至更高能级轨道。由于这些电子在高能态下并不稳定，它们会自主回落至原始低能轨道，同时根据能量守恒定律释放出能量差对应的光子。这一现象就是辉光放电，它被应用于霓虹灯等装置中。等离子环的发光过程与此类似。

  - 等离子体的性质：除了常见的固体、液体和气态，等离子体是存在于宇宙中的另一种物质状态，火焰便是包含等离子体的例子。当气体受到高温的影响时，分子间的碰撞会使得外层电子脱离其轨道，形成一种由带电粒子组成的等离子体。这种带电的离子混合物具有导电性。
  - 环形电磁场的产生：通过在环形线圈中通入高频交变电流，可以根据麦克斯韦方程组得出其周围电场分布为环形。我们使用自激的Class E震荡电路来生成频率为10MHz左右的交流电。

  - 等离子环的生成过程：在一个封有低压氙气的球形玻璃瓶内，氙气在强电场的作用下被电离，形成等离子体。这些导电的氙气等离子体在外加环形电场的影响下，形成稳定的环状结构。在等离子体中，带电粒子的碰撞产生辉光放电，进而发出淡紫色的光芒，这使得等离子环可见。

**请您在使用和展示等离子环时，确保理解其工作原理和相应的安全措施，以保障使用者的安全。**

## 准备材料

 

- 充有氙气的玻璃瓶80mm(在淘宝**对角巷魔法商店**可找到,更大的玻璃球无法安装到本项目的支架中)
- 1.2mm 漆包线 —— 绕制线圈
- 黑环电感 10uH
- 电路板PCB (可使用hardware文件夹中的文件制作)
- 线圈支架，包括底板和五片支架
- 散热片与风扇
- MOS管 IRFP260N
- MOS管散热硅胶垫
- 电位器 1k
- 电阻1k * 3
- 电阻1.8k, 3k
- 贴片电容 100pf * 4
- 贴片电容 4.7nF * 2
- TVS 15V P6KE15CA
- 稳压二极管 9.1V
- 输入滤波电容 电解电容 63V 220uf
- 钮子开关
- 绿色接线端子 —— 用于接线圈
- 白色风扇插座
- DC电源接口
- 发光二极管
- 螺丝与尼龙柱
- 打火机中拆出来的压电陶瓷 (用于初始点亮)
- XL4015限流模块 （有可调电源可以不准备此模块）
- 24v电源适配器（4A以上，或者有可调电源也可）

## 制作教程
难度 ★★★☆☆

### 工具
- 万用表 
- 电烙铁 
- 焊锡丝 
- 小刀 
- 斜口钳 
- 内六方螺丝刀套装
- 镊子（用于焊接贴片电容）



### 步骤
- 准备好五个线圈支架，插在底座上，烧热烙铁，用焊锡焊接固定。尽可能保证支架和底板处于垂直状态。（五片线圈支架要用一些力才能塞进去）

 

- 把漆包线按照线圈架的直径弯曲，不要拉直漆包线，保持漆包线弯曲有助于穿线，一旦拉直就穿不进去了。



- 将漆包线按照小孔从上到下穿入，共四圈。孔位较小，可以通过推拉的方式穿入。





- 制作带限流保护的电源（已有可调电源的话可以跳过此步），准备好24V电源和XL4015限流模块，将电源线剪开，把模块串联在中间，将XL4015模块调输出电压的电位器顺时针拧到头(拧到头会有咔哒响声)，将限流电位器拧到3.5A的位置，确定该限流电位器位置的方法是:将万用表打到10A电流档，表笔插入10A的孔位，两个表笔对到输出上（此时相当于短路了输出，可能有电火花但没事），万用表显示的数值就是限流模块的限流值。注意，使用没有限流的电源会十分容易烧毁mos管，一定要串联XL4015模块再接电。如果已经有可调电源则可以跳过这一步。下图中模块左边的电位器是调节输出电压，右边的电位器是调节限流，顺时针拧增大。
- 如果您是使用可调电源，请使用限流模式（CC）,设置输出电压24V，限流3.5A。




- 将元件按照型号分别插入电路板 (先不要安装MOS管)，为了方便焊接，可以将管脚进行简单折弯固定。注意，**风扇的接线座应该安装在PCB背面**。
各元件安装位置如下表所示。

| 元件名称 | 安装位置 |
|---|---|
| 1k电阻 * 3 | R1, R4, 顶面PCB |
| 发光二极管 | 顶面PCB |
| 3k电阻 | R2 |
| 1.8k电阻 | R3 |
| 稳压二极管 | D2 |
| TVS（黑色） | D1 |
| 绿色接线座 | P1 |
| 白色接线座 | Q3（安装在背面）|
| 220uf电解电容 | C5 |
| 100pf电容 * 4 | C1, C2, C3, C4  |
| 4.7nf电容 * 2 | C6, C7 |
| 10uH电感 | L1 |
| IRFP260 | Q1 (这个先不安装) |
| 开关 | |
| DC5525黑色电源插座 | |
| B1K单联电位器 | |

- 建议先焊接矮的元件，再焊接高的元件，例如先焊接贴片电容，电阻，稳压管，接线座等，最后焊接电解电容，开关。如果没有焊接经验，务必先在B站搜索焊接教程学习一下。经过历史统计，制作完后出现问题的人中有60%是因为没有掌握正确的焊接方法导致了元件和PCB接触不良。
  
  > 电阻分辨方式
  >  - 1k电阻上有个棕色线
  >	 - 1.8k电阻上有棕色线和灰色线
  >	 - 3k电阻上有橙色线
  >	 实在分辨不明白就用万用表量吧^_^

  > 电容分辨方式
  >  - 4.7nF电容相对薄一些
  >	 - 220pF/100pF电容相对厚一些
  >  - 谐振电容可以选择220pF两个或100pF四个

  > 二极管方向分辨方式
  >  - 黑色的TVS不分方向
  >	 - 红色的稳压二极管需要分方向，稳压二极管上的黑线对准PCB上面丝印中的白线位置。

  > 部分朋友可能不会焊接贴片元件，可以在B站搜索贴片元件焊接教程学习下。简单说来，先焊上一边固定住贴片元件，再焊接另一边。
  >【两脚的贴片元件如何快速焊接？有哪些注意事项？几分钟就掌握技巧-哔哩哔哩】 https://b23.tv/XZ3q8Bh

  > 务必注意电解电容的方向，焊反可能会剧烈发热甚至爆炸。电解电容脚长的一边是正极，有条纹标记的一边是负极。


- 焊接时，**注意烙铁高温，小心烫伤。**

- 将所有元件焊接好后，剪去管脚。请尽量保证焊点饱满圆润，去除管脚时请从根部开始。



- 将散热片四周螺丝孔内拧入6mm铜柱(或者6mm尼龙柱)。



- 安装MOSFET。将MOS管有字的一面**向上**，将另一面垫上硅胶垫后用螺丝固定在散热片上，管脚**对着下方**，此时管脚左中右分别为G D S极。





- 将管脚弯曲后插入PCB，**先将PCB和散热片孔位对准，确保能拧上四个螺丝**，随后再焊接MOS管



- 固定风扇,所有层的连接关系如下图所示，风扇的风冲着散热片吹（朝上吹）。







- 将线圈支架用螺丝安装到顶部，两根线对着绿色的线圈接线座




- 适当地剪短漆包线，使其能插入接线座即可。
- 用小刀刮开线头漆皮，露出漆包线内部的铜芯。
- **注意：一定要把线头漆皮刮干净，否则可能接触不良无法工作！**



- 将线圈的两根线插入绿色接线座的1,3引脚（中间的孔不插），将风扇电源线插入PCB背面的风扇接口。

- 再次确认所有部分连接正常后，就可以准备通电了o(*￣▽￣*)ブ

- 如果您是使用可调电源，请使用限流模式（CC）,设置输出电压24V，限流3.5A。
- 放上瓶子，并确保电位器位于逆时针最大处。

- 在通电之前，请仔细阅读安全说明：
  >  电路工作的时候一定要远离线圈，线圈的高温可能使人烫伤。

  >  可以转动瓶子，但瓶子也会发热，注意安全，转动瓶子时手远离线圈（至少距离1cm以上）。

  >	 可以在电路工作时拧电位器，但不要一个手拿着瓶子一个手触摸电路上的电位器，因为瓶子上的高压静电会损坏电路。

  >	 电路会发热，不建议长时间运行电路，建议连续工作不超过两分钟。

  >	 使用完毕后，记得关掉开关，断开电源。

- 确保阅读了安全说明后，插上电源，打开开关，此时应该风扇会转。

- 向顺时针拧电位器，大概拧到一半位置时，电路就会开始工作。电路开始工作后，线圈旁边的LED会亮起。此时使用点火器对准瓶子点一下即可出环。如果点火器点不出环，可以把电位器再顺时针拧大一些再点。
  




- 有时候，您的瓶子会泛白光而不出环（如下图所示），调整瓶子位置后重新点火几次一般就好了。


- 出环后，微微拧动电位器环的形态会发生一些变化，如果环消失了，重新点火即可再次出环。



### 参考电路图
由于此项目的硬件还在不断更新，电路图仅供参考，实际以PCB为准


### FAQ
如果有任何问题，加QQ群 736688139，所有项目开发人员都在群中，您可以以最快的速度获得答案。

鸣谢： Tate McAluney

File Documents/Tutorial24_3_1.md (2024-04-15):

# 等离子环制作说明

此文档更新于2024年3月1日

作者 *对角巷魔法商店*
本文中所使用的零件均可在淘宝店铺***对角巷魔法商店***找到

[成品效果视频1](https://www.bilibili.com/video/BV1Lm411z7tf)
[成品效果视频2](https://www.bilibili.com/video/BV12f421o7rf)

[立创开源平台](https://oshwhub.com/skylake/plasmatoroid-drive-circuit)

等离子环开源技术交流QQ群  736688139



## 版权声明©

此文档仅供个人学习制作等离子环使用，未经作者同意，任何人不得修改、重新发布、发行本文档内容。严禁使用本文档进行任何商业行为。

## 免责声明
在您使用本文档制作等离子环前，请仔细阅读以下重要安全警告和免责说明。使用本文档即表示您已充分了解并同意以下条款：
- 等离子环的危险性：等离子环在运行时玻璃瓶身会产生高温，存在低温烧伤风险。任何时候都不建议用手直接触摸正在运行的玻璃瓶，以免烧伤。
- 磁场警告：等离子环在运行时会产生较强磁场。对于佩戴心脏起搏器及其他医疗设备的人群，强磁场可能会影响设备正常工作。我们建议这部分用户应远离正在工作的等离子环，避免可能的健康风险。
- 高电压风险：等离子环的驱动电路在工作时会产生高电压。高电压存在触电或灼伤的危险，请在电路工作时不要触碰任何元件，包括初级线圈，以免触电或烧伤。
- 元件温度：请注意，电路的某些元件在运行时可能会变得非常热，这可能会造成烫伤。请在设备运行时，特别是长时间运行后，不要触摸这些元件。
- 电磁干扰：等离子环运行时会发射10MHz左右的电磁波，该波段对人体无伤害，但可能干扰此频段运行的部分电子设备，例如触摸板和刷卡机，请将这些设备远离正在工作的驱动电路。

使用本文档意味着您已经了解并同意自担使用风险，对于不遵守安全指南而造成的任何直接或间接损害，作者不承担任何责任。

谨慎DIY，安全至上！

## 等离子环（Plasma Toroid）的工作原理解析

  - 辉光放电现象：在特定条件下，气体会在强电场的作用下发生辉光放电。这一过程中，气体分子的电子受激发后跃迁至更高能级轨道。由于这些电子在高能态下并不稳定，它们会自主回落至原始低能轨道，同时根据能量守恒定律释放出能量差对应的光子。这一现象就是辉光放电，它被应用于霓虹灯等装置中。等离子环的发光过程与此类似。

  - 等离子体的性质：除了常见的固体、液体和气态，等离子体是存在于宇宙中的另一种物质状态，火焰便是包含等离子体的例子。当气体受到高温的影响时，分子间的碰撞会使得外层电子脱离其轨道，形成一种由带电粒子组成的等离子体。这种带电的离子混合物具有导电性。
  - 环形电磁场的产生：通过在环形线圈中通入高频交变电流，可以根据麦克斯韦方程组得出其周围电场分布为环形。我们使用自激的Class E震荡电路来生成频率为10MHz左右的交流电。

  - 等离子环的生成过程：在一个封有低压氙气的球形玻璃瓶内，氙气在强电场的作用下被电离，形成等离子体。这些导电的氙气等离子体在外加环形电场的影响下，形成稳定的环状结构。在等离子体中，带电粒子的碰撞产生辉光放电，进而发出淡紫色的光芒，这使得等离子环可见。

**请您在使用和展示等离子环时，确保理解其工作原理和相应的安全措施，以保障使用者的安全。**

## 准备材料



<font color="red">注意：四月份后推出了黑色PCB的新版本，黑色PCB和绿色略有区别，这些区别以红字标注在本文中</font>

- 充有氙气的玻璃瓶80mm(在淘宝搜索等离子环可找到,更大的玻璃球无法安装到本项目的支架中)
- 1.2mm 漆包线 —— 绕制线圈
- 黄环电感 10uH
- 电路板PCB (可用洞洞板或者搭棚替代)
- 线圈支架，包括底板和五片支架
- 散热片与风扇
- MOS管 IRFP260N
- MOS管散热硅胶垫
- 电位器 1k
- 电阻1k * 2
- 电阻2.7k, 5.6k (<font color="red">新版被换为了1.8k和3k，分别对应2.7k和5.6k的位置</font>)
- 瓷片电容 30pf * 4 (<font color="red">新版被换为了两个220pf的贴片电容</font>)
- 贴片电容 4.7nF * 2
- TVS 15V P6KE15CA
- 稳压二极管 9.1V
- 输入滤波电容 电解电容 63V 220uf * 2
- 钮子开关MTS102-C4
- 绿色接线端子KF142R-5.08 —— 用于接线圈
- 白色风扇插座
- DC5525 电源接口
- 螺丝与尼龙柱
- 打火机中拆出来的压电陶瓷 (用于初始点亮)
- XL4015限流模块 （有可调电源可以不准备此模块）
- 24v电源适配器（4A以上，或者有可调电源也可）

## 制作教程
难度 ★★★☆☆

### 工具
- 万用表 
- 电烙铁 
- 焊锡丝 
- 小刀 
- 斜口钳 
- 内六方螺丝刀套装



### 步骤
- 准备好五个线圈支架，插在底座上，烧热烙铁，用焊锡焊接固定。尽可能保证支架和底板处于垂直状态。（五片线圈支架要用一些力才能塞进去）



- 把漆包线按照线圈架的直径弯曲，不要拉直漆包线，保持漆包线弯曲有助于穿线


- 将漆包线按照小孔从上到下穿入，共三圈。孔位较小，可以通过推拉的方式穿入。
- <font color="red">注意，新版的黑色PCB请将线圈绕四圈</font>





- 制作带限流保护的电源（已有可调电源的话可以跳过此步），准备好24V电源和XL4015限流模块，将电源线剪开，把模块串联在中间，将XL4015模块调输出电压的电位器顺时针拧到头，将限流电位器拧到3.5A的位置，确定该限流电位器位置的方法是:将万用表打到10A电流档，两个表笔对到输出上（此时相当于短路了输出），万用表显示的数值就是限流模块的限流值。注意，使用没有限流的电源会十分容易烧毁mos管，如果已经有可调电源则可以跳过这一步。下图中模块左边的电位器是调节输出电压，右边的电位器是调节限流。
- 如果您是使用可调电源，请使用限流模式（CC）,设置输出电压24V，限流3.5A。




- 将元件按照型号分别插入电路板 (先不要安装MOS管)，为了方便焊接，可以将管脚进行简单折弯固定。注意，风扇的接线座应该安装在PCB背面。
- 建议先焊接矮的元件，再焊接高的元件，例如先焊接电阻，稳压管，接线座等，最后焊接电容，开关。
  
  > 电阻分辨方式
  >  - 大一点的是1k电阻
  >	 - 带有绿色和蓝色环的是5.6k电阻
  >	 - 带有红色和紫色环的是2.7k电阻
  >  -<font color="red">新款的PCB用1.8k和3k电阻代替了2.7k和5.6k</font>

    >  -<font color="red">新款的PCB有两种贴片电容，厚一些的是220pf，薄一些的是4.7nf的，薄一些的安装在C9和C10，另外，新款的在线圈支架上需要焊接一个led和一个1k电阻</font>




- 焊接时，**注意烙铁高温，小心烫伤。**

- 将所有元件焊接好后，剪去管脚。请尽量保证焊点饱满圆润，去除管脚时请从根部开始。



- 将散热片四周螺丝孔内拧入铜柱。<font color="red">新款改用了6mm高的尼龙柱</font>



- 安装MOSFET。将MOS管有字的一面**向上**，将另一面垫上硅胶垫后用螺丝固定在散热片上，管脚**对着下方**，此时管脚左中右分别为G D S极。



- 将管脚弯曲后插入PCB，**先将PCB和散热片孔位对准，确保能拧上四个螺丝**，随后再焊接MOS管



- 固定风扇,所有层的连接关系如下图所示，风扇的风冲着散热片吹（朝上吹）。





- 将线圈支架用螺丝安装到顶部，两根线对着绿色的线圈接线座



- 适当地剪短漆包线，使其能插入接线座即可。
- 用小刀刮开线头漆皮，露出漆包线内部的铜芯。
- **注意：一定要把线头漆皮刮干净，否则可能接触不良无法工作！**



- 将线圈的两根线插入绿色接线座的1,3引脚（中间的孔不插），将风扇电源线插入PCB背面的风扇接口。

- 再次确认所有部分连接正常后，就可以准备通电了o(*￣▽￣*)ブ

- 如果您是使用可调电源，请使用限流模式（CC）,设置输出电压24V，限流3.5A。
- 放上瓶子，并确保电位器位于逆时针最大处。

- 在通电之前，请仔细阅读安全说明：
  >  电路工作的时候一定要远离线圈，线圈的高温可能使人烫伤。

  >  可以转动瓶子，但瓶子也会发热，注意安全，转动瓶子时手远离线圈（至少距离1cm以上）。

  >	 可以在电路工作时拧电位器，但不要一个手拿着瓶子一个手触摸电路上的电位器，因为瓶子上的高压静电会损坏电路。

  >	 电路会发热，不建议长时间运行电路，建议连续工作不超过两分钟。

  >	 使用完毕后，记得关掉开关，断开电源。

- 确保阅读了安全说明后，插上电源，打开开关，此时应该风扇会转。

- 向顺时针拧电位器，大概拧到行程80%的位置时，电路就会开始工作，此时使用点火器对准瓶子点一下即可出环。如果点火器点不出环，可以把电位器再顺时针拧大一些再点。



- 有时候，您的瓶子会泛白光而不出环（如下图所示），调整瓶子位置后重新点火几次一般就好了。


- 出环后，微微拧动电位器环的形态会发生一些变化，如果环消失了，重新点火即可再次出环。



### 参考电路图
由于此项目的硬件还在不断更新，电路图仅供参考，实际以PCB为准


### FAQ
如果有任何问题，加QQ群 736688139，所有项目开发人员都在群中，您可以以最快的速度获得答案。

鸣谢： Tate McAluney

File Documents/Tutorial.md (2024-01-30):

# 等离子环制作说明

作者 *对角巷魔法商店*

[成品效果视频](https://www.bilibili.com/video/BV1YQ4y157gs)

[立创开源平台](https://oshwhub.com/skylake/plasmatoroid-drive-circuit)

[调试过程注意事项](./Notes.md)

等离子环开源技术交流QQ群  736688139



## 时效性声明
电路处于高速迭代期，本教程文档将在电路调试稳定后进行更新。

其他平台如Bilibili，立创等文档均为Github版本副本。如果出现不一样的地方请以Github版本为准

## 版权声明©

此文档仅供个人学习制作等离子环使用，未经作者同意，任何人不得修改、重新发布、发行本文档内容。严禁使用本文档进行任何商业行为。

## 免责声明
在您使用本文档制作等离子环前，请仔细阅读以下重要安全警告和免责说明。使用本文档即表示您已充分了解并同意以下条款：
- 等离子环的危险性：等离子环在运行时玻璃瓶身会产生高温，存在低温烧伤风险。任何时候都不建议用手直接触摸正在运行的玻璃瓶，以免烧伤。
- 磁场警告：等离子环在运行时会产生较强磁场。对于佩戴心脏起搏器及其他医疗设备的人群，强磁场可能会影响设备正常工作。我们建议这部分用户应远离正在工作的等离子环，避免可能的健康风险。
- 高电压风险：等离子环的驱动电路在工作时会产生高电压。高电压存在触电或灼伤的危险，请在电路工作时不要触碰任何元件，包括初级线圈，以免触电或烧伤。
- 元件温度：请注意，电路的某些元件在运行时可能会变得非常热，这可能会造成烫伤。请在设备运行时，特别是长时间运行后，不要触摸这些元件。

使用本文档意味着您已经了解并同意自担使用风险，对于不遵守安全指南而造成的任何直接或间接损害，作者不承担任何责任。

谨慎DIY，安全至上！

## 等离子环（Plasma Toroid）的工作原理解析

  - 辉光放电现象：在特定条件下，气体会在强电场的作用下发生辉光放电。这一过程中，气体分子的电子受激发后跃迁至更高能级轨道。由于这些电子在高能态下并不稳定，它们会自主回落至原始低能轨道，同时根据能量守恒定律释放出能量差对应的光子。这一现象就是辉光放电，它被应用于霓虹灯等装置中。等离子环的发光过程与此类似。

  - 等离子体的性质：除了常见的固体、液体和气态，等离子体是存在于宇宙中的另一种物质状态，火焰便是包含等离子体的例子。当气体受到高温的影响时，分子间的碰撞会使得外层电子脱离其轨道，形成一种由带电粒子组成的等离子体。这种带电的离子混合物具有导电性。
  - 环形电磁场的产生：通过在环形线圈中通入高频交变电流，可以根据麦克斯韦方程组得出其周围电场分布为环形。我们使用自激的Class E震荡电路来生成频率为10MHz左右的交流电。

  - 等离子环的生成过程：在一个封有低压氙气的球形玻璃瓶内，氙气在强电场的作用下被电离，形成等离子体。这些导电的氙气等离子体在外加环形电场的影响下，形成稳定的环状结构。在等离子体中，带电粒子的碰撞产生辉光放电，进而发出淡紫色的光芒，这使得等离子环可见。

**请您在使用和展示等离子环时，确保理解其工作原理和相应的安全措施，以保障使用者的安全。**

## 准备材料



- 充有氙气的玻璃瓶80mm(在淘宝搜索等离子环可找到,更大的玻璃球无法安装到本项目的支架中)
- 漆包线 —— 绕线电感 （作者使用的漆包线都是1.2mm的）
- 漆包线 —— 初级线圈
- 电路板PCB (可用洞洞板或者搭棚替代)
- MOS管 IRFP260N
- 电位器 10k
- 电阻470
- 电阻1k
- 瓷片电容 30pf * 4
- 瓷片电容 4.7nF * 2
- TVS 15V （双向）
- 稳压二极管 12V
- 输入滤波电容 电解电容 63V 220uf * 3 
- 接线端子
- 打火机中拆出来的压电陶瓷 (用于初始点亮)
- 24v电源适配器

## 制作教程
难度 ★★★☆☆

### 工具
- 万用表 
- 电烙铁 
- 焊锡丝 
- 小刀 
- 斜口钳 
- 内六方螺丝刀套装



### 步骤
- 烧热烙铁，准备好六个初级线圈架，插在底座上，用焊锡焊接固定。尽可能保证支架和底板处于垂直状态。


- 把漆包线按照线圈架的直径弯曲三圈后剪短

- 把截下的漆包线留出约一指长作为接头拉出备用，按照小孔从上到下穿入，共三圈。穿好后另一头用同样方式拉出。孔位较小，可以通过推拉的方式穿入。



- 用小刀刮开线头漆皮，露出漆包线内部的铜芯。用烙铁和焊锡为铜芯镀锡
  
- 制作扼流电感。取出较长的漆包线，绕成直径大概25mm的线圈，绕20圈即可，最后用尼龙扎带固定住线圈。



- 将元件按照型号分别插入电路板 (先不要安装MOS管)
  
  > 电阻分辨方式
  >  - 色环电阻上带有紫色环的为470电阻
  >	 - 只有棕色和黑色环的为1K电阻

  > 电容分辨方式
  > 蓝色电容上有数字说明其属性
  > - 33pF电容正面有33字样
  > - 4.7nF电容正面有472字样



- 将元件按照其属性分别放入PCB上等待焊接。为了方便焊接，可以将管脚进行简单折弯固定。
- 开始焊接，**注意烙铁高温，小心烫伤。**



- 将所有元件焊接好后，剪去管脚。请尽量保证焊点饱满圆润，去除管脚时请从根部开始。



- 将散热片四周螺丝孔内拧入铜柱。
- 开始安装MOSFET。将MOS管有字的一面***向上***，将另一面涂上硅脂后用螺丝穿过螺丝孔固定在散热片上，MOS有字的一面面对自己，管脚***向下***，此时管脚左中右分别为G D S极。



- 将管脚弯曲后插入PCB焊接。
**注意：弯曲时请勿从管脚根部开始，应当从小节开始**
- 将PCB对准散热片铜柱螺丝孔，用新的铜柱固定。
- 固定风扇,所有层的连接关系如下图所示，风扇的风冲着散热片吹（朝上吹）。

  
  
- 将所有电路连接好，放上瓶子，并确保电位器位于逆时针最大处
- 通电，请注意安全！手远离初级线圈附近。千万不要一个手拿着瓶子一个手触摸电路上的电位器，因为瓶子上的高压静电会损坏电路。
- 慢慢向顺时针拧电位器，拧到一半的时候即可看到等离子环生成，此时再逆时针轻轻拧动，保持等离子环稳定即可。有的时候可能不会自启动，只需要用压电陶瓷打一下电火花即可出环。
- **注意：顺时针拧电位器会增大功率，长时间大功率运转会烧坏电路，建议把电位器保持在等离子环刚好不消失的位置！使用完后一定要拔掉电源！**



一些补充说明会在另一个文件中讲述，请移步[调试过程注意事项](./Notes.md)。

### 参考电路图



鸣谢： Tate McAluney

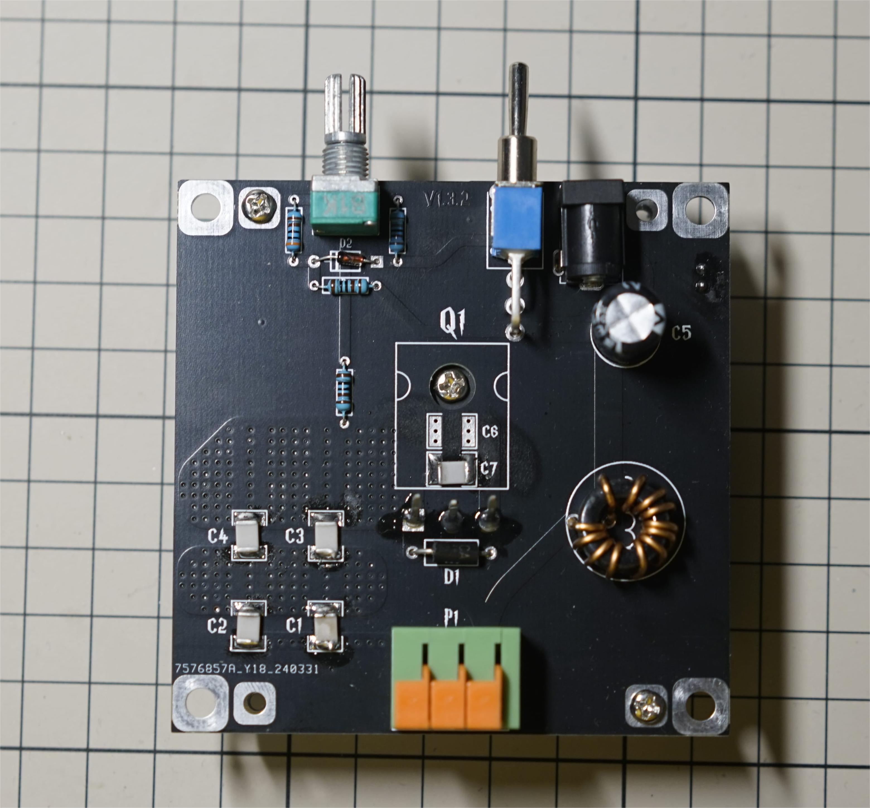
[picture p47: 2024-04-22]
imgs/imgs_24_4_13/Assemble5.JPG

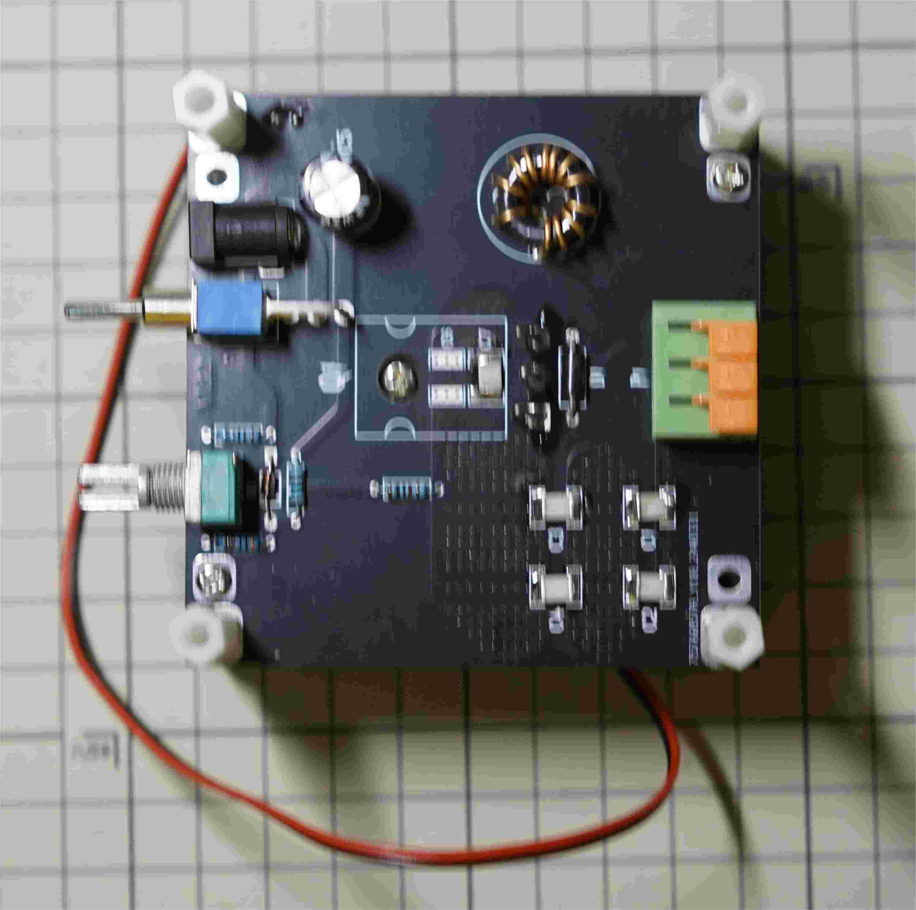
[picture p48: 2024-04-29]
imgs/imgs_24_4_13/compress/Assemble4.jpg

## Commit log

2024-01-17 modified: Documents/Tutorial.md new file: Hardware/PlasmaDriver-RoundHoles.TXT new file: Hardware/PlasmaDriver-SlotHoles.TXT new file: Hardware/PlasmaDriver-macro.APR_LIB new file: Hardware/PlasmaDri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
    [PlasmaDriver.GBL, PlasmaDriver.GBO, PlasmaDriver.GBP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]
2024-01-27 modified: Documents/Tutorial.md renamed: Hardware/PlasmaDriver-RoundHoles.TXT -> Hardware/Driver/PlasmaDriver-RoundHoles.TXT renamed: Hardware/PlasmaDriver-SlotHoles.TXT -> Hardware/Driver/PlasmaDriv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
    [PlasmaDriver.GBL, PlasmaDriver.GBO, PlasmaDriver.GBP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]
2024-01-29 new file: Hardware/CoilHolder/CoilHolder.DRR new file: Hardware/CoilHolder/CoilHolder.EXTREP new file: Hardware/CoilHolder/CoilHolder.GBL new file: Hardware/CoilHolder/CoilHolder.GBO new file: Hardwa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
    [CoilHolder.GBL, CoilHolder.GBO, CoilHolder.GBP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]
2024-03-01 push测试
2024-03-01 3月1日更新教程，按照最新的PCB
2024-03-01 更新教程文档
2024-04-01 deleted: Hardware/DriverV1.1.3/PlasmaDriver-RoundHoles.TXT deleted: Hardware/DriverV1.1.3/PlasmaDriver.GBL deleted: Hardware/DriverV1.1.3/PlasmaDriver.GBO deleted: Hardware/DriverV1.1.3/PlasmaDriver.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
    [PlasmaDriver.GBL, PlasmaDriver.GBO, PlasmaDriver.GBS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]
2024-04-01 new file: Hardware/DriverV1.3.2/BOM List.csv
    [BOM List.csv]
2024-04-01 Update BOM List.csv
    [BOM List.csv]
2024-04-01 删除pdf
2024-04-13 初步写出8cm教程，还需要更新图片
2024-04-15 小幅度更新9cm教程
2024-04-19 Update Tutorial24_4_13.md
    小幅度修改8cm教程
2024-04-21 modified: Documents/Tutorial24_4_13.md new file: imgs/imgs_24_4_13/Assemble1.JPG new file: imgs/imgs_24_4_13/Assemble2.JPG new file: imgs/imgs_24_4_13/Assemble3.JPG new file: imgs/imgs_24_4_13/Assemb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
2024-04-22 优化8cm教程，裁剪了图片
2024-04-22 优化8cm教程
2024-04-29 无用更新
2024-04-29 更新了图片，重拍了8cm版本的正反面焊接图
2024-05-08 修复4.7k的bug
2024-05-31 修改小bug
2024-06-08 严正谴责抄袭商家
2024-09-23 缩小一些图片
2024-10-11 更新youtube链接
